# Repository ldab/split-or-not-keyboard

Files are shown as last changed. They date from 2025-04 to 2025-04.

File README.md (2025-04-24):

# split-or-not-keyboard

FoMO ZMK Ortholinear keyboard, if you can't decide between split or not.







<p align="center">
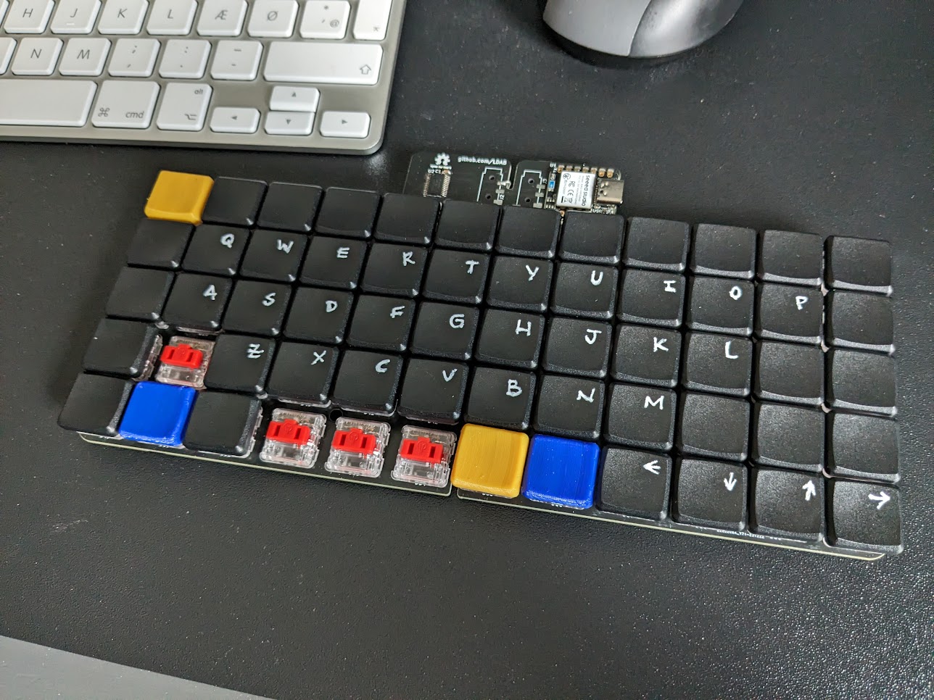
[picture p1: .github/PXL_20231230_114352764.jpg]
  
</p>

## Todo

## Note

- Polling mode add extra 60uA
-

## Why?

Maybe you are here because you are considering a ZMK keyboard and you don't know if you are ready for a split keyboard? Or you don't know if you prefer a rectangular or "ergo" design? Or you have fear or missing out and want to try all of them but don't want to spend all your money?

## How?

## Designed with KiCAD 7.09

- Important libs are added as plugin as per described on https://github.com/ebastler/marbastlib

## BOM

* 1x Seeed Studio XIAO nRF52840
* 1x PCA9555 GPIO Expander
* 60x 1N4148W diodes
* 60x Kailh choc switches
* 60x Kailh choc keycap
* 60x Kailh choc Hotswap Sockets

## Variants

### Basic60

basic

<p align="center">
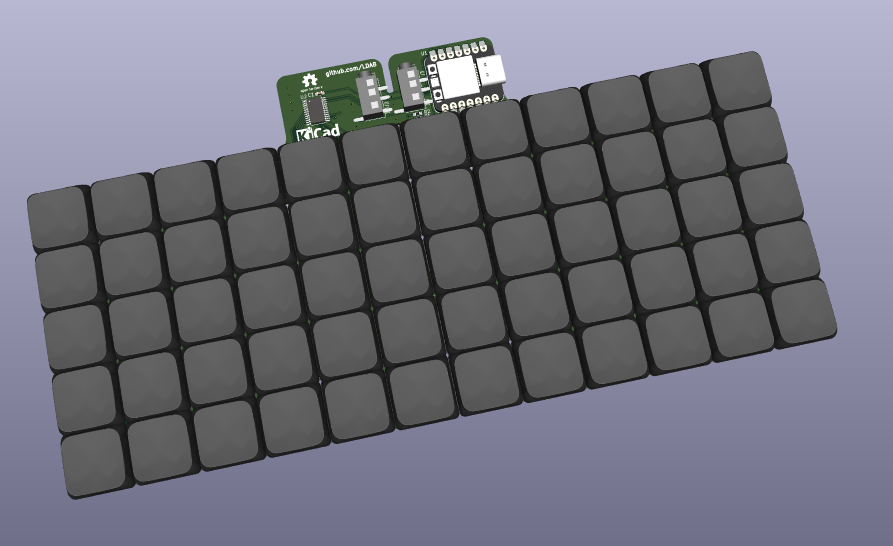
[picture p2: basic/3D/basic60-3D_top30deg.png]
  
</p>

<p align="center">
  
</p>

### Ergo56

ergo

<p align="center">
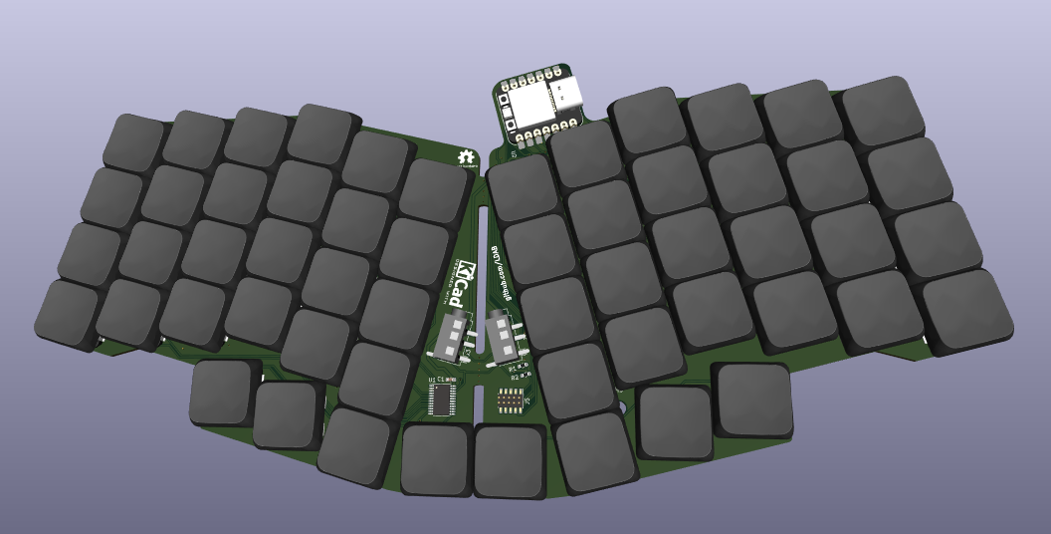
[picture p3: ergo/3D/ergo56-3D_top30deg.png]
  
</p>

<p align="center">
  
</p>

## Battery life

## Outro

- Some similarities with below may be found:
  - https://github.com/piit79/rev57lp/

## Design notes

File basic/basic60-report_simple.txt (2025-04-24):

PCB Specifications:
Size:

- 216.0x108.2 mm

Class: 8B

Track width: >= 0.25 mm

Insulation distance: >= 0.2 mm

Minimum drill size: >= 0.5 mm (finished metalized hole: 0.4 mm)

Minimum slot width: >= N/A mm

Ring collar: >= 0.1 mm

Stackup:

| Name | Type | Color | Thickness | Material | Epsilon_r | Loss tangent |
|---|---|---|---|---|---|---|
| F.SilkS | Top Silk Screen | | | | | |
| F.Paste | Top Solder Paste | | | | | |
| F.Mask | Top Solder Mask | | 10 | | | |
| F.Cu | copper | | 35 | | | |
| dielectric 1 | core | | 1510 | FR4 | 4.5 | 0.020 |
| B.Cu | copper | | 35 | | | |
| B.Mask | Bottom Solder Mask | | 10 | | | |
| B.Paste | Bottom Solder Paste  | | | | | |
| B.SilkS | Bottom Silk Screen | | | | | |

Materials:

- FR4, 1.6 mm
- None
- 2 layers
- 35 µm copper thickness

Solder mask:

- TOP / BOTTOM
- Green

Marking:

- TOP / BOTTOM screen printing
- Silk: White

Other markings:

- ROHS / UL / Date - Yes if available

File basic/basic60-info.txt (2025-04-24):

KiBot installation checker

Core:
Linux: 6.2.0.39 (Linux leo-pc 6.2.0-39-generic #40~22.04.1-Ubuntu SMP PREEMPT_DYNAMIC Thu Nov 16 10:53:04 UTC 2 x86_64 x86_64 x86_64 GNU/Linux)
  /usr/bin/uname
Python: 3.10.12 (main, Nov 20 2023, 15:14:05) [GCC 11.4.0]
  /usr/lib/python3.10/os.py
  /usr/bin/python3
KiCad: 7.0.9-7.0.9~ubuntu22.04.1
  /usr/lib/python3/dist-packages/pcbnew.py
  /usr/bin/kicad
Kibot: 1.6.3
  /usr/lib/python3/dist-packages/kibot/__main__.py
  /usr/bin/kibot

Modules:
Colorama: 0.4.4
  /usr/lib/python3/dist-packages/colorama/__init__.py
LXML: 4.8.0
  /usr/lib/python3/dist-packages/lxml/__init__.py
Lark: 1.1.8
  /home/leo/.local/lib/python3.10/site-packages/lark/__init__.py
PyYAML: 6.0.1
  /home/leo/.local/lib/python3.10/site-packages/yaml/__init__.py
QRCodeGen: Ok
  /usr/lib/python3/dist-packages/qrcodegen.py
Requests: 2.25.1
  /usr/lib/python3/dist-packages/requests/__init__.py
XLSXWriter: 3.0.2
  /usr/lib/python3/dist-packages/xlsxwriter/__init__.py
Xvfbwrapper: Ok
  /usr/lib/python3/dist-packages/xvfbwrapper.py
markdown2: 2.4.1
  /usr/lib/python3/dist-packages/markdown2.py
mistune: 0.8.4
  /usr/lib/python3/dist-packages/mistune.py
numpy: 1.21.5
  /usr/lib/python3/dist-packages/numpy/__init__.py

Tools:
Bash: 5.1.16 (GNU bash, version 5.1.16(1)-release (x86_64-pc-linux-gnu))
  /usr/bin/bash
Blender: 3.0.1 (Color management: using fallback mode for management)
  /usr/bin/blender
Ghostscript: 9.55.0
  /usr/bin/gs
Git: 2.34.1 (git version 2.34.1)
  /usr/bin/git
ImageMagick: 6.9.11.60 (Version: ImageMagick 6.9.11-60 Q16 x86_64 2021-01-25 https://imagemagick.org)
  /usr/bin/convert
Interactive HTML BoM: 2.7.0 (v2.7.0)
  /usr/bin/python3
KiBoM: 1.9.1 (KiBOM Version: 1.9.1)
  /usr/bin/KiBOM_CLI.py
KiCad Automation tools (kiauto): 2.2.8 (pcbnew_do 2.2.8 - Copyright 2018-2023, INTI/Productize SPRL - License: Apache)
  /usr/bin/pcbnew_do
KiCad PCB/SCH Diff (kidiff): 2.5.0 (kicad-diff.py 2.5.0 - Copyright 2020-2023, INTI/Salvador E. Tropea - License:)
  /usr/bin/kicad-diff.py
KiCost: 1.1.18 (KiCost v1.1.18)
  /usr/bin/kicost
KiKit: 1.4.0.1 (kikit, version 1.4.0-1)
  /usr/bin/kikit
OpenSCAD: 2021.1.0 (OpenSCAD version 2021.01)
  /usr/bin/openscad
Pandoc: 2.9.2.1 (pandoc 2.9.2.1)
  /usr/bin/pandoc
RAR: 5.50.0 (RAR 5.50   Copyright (c) 1993-2017 Alexander Roshal   11 Aug 2017)
  /usr/bin/rar
RSVG tools: 2.52.5 (rsvg-convert version 2.52.5)
  /usr/bin/rsvg-convert
Xvfb: Ok (xvfb-run)
  /usr/bin/rsvg-convert

* Blender not installed or too old
  Install the `blender` package, i.e.: `sudo apt-get install blender`
  - Mandatory for `blender_export`

Environment:
COLORFGBG
COLORTERM
DBUS_SESSION_BUS_ADDRESS
DESKTOP_SESSION
DISPLAY
GDMSESSION
GIO_LAUNCHED_DESKTOP_FILE
GIO_LAUNCHED_DESKTOP_FILE_PID
GITHUB_TOKEN
GJS_DEBUG_OUTPUT
GJS_DEBUG_TOPICS
GNOME_DESKTOP_SESSION_ID
GNOME_SHELL_SESSION_MODE
GPG_AGENT_INFO
GTK_IM_MODULE
GTK_MODULES
HISTCONTROL
HOME
HOMEBREW_CELLAR
HOMEBREW_PREFIX
HOMEBREW_REPOSITORY
INFOPATH
INTERACTIVE_HTML_BOM_NO_DISPLAY
INVOCATION_ID
JOURNAL_STREAM
KICAD6_3DMODEL_DIR
KICAD6_3RD_PARTY
KICAD6_FOOTPRINT_DIR
KICAD6_SYMBOL_DIR
KICAD6_TEMPLATE_DIR
KICAD7_3DMODEL_DIR
KICAD7_3RD_PARTY
KICAD7_FOOTPRINT_DIR
KICAD7_SYMBOL_DIR
KICAD7_TEMPLATE_DIR
KICAD_USER_TEMPLATE_DIR
KIPRJMOD
KISYS3DMOD
KISYSMOD
KONSOLE_DBUS_SERVICE
KONSOLE_DBUS_SESSION
KONSOLE_DBUS_WINDOW
KONSOLE_VERSION
LANG
LANGUAGE
LC_ADDRESS
LC_IDENTIFICATION
LC_MEASUREMENT
LC_MONETARY
LC_NAME
LC_NUMERIC
LC_PAPER
LC_TELEPHONE
LC_TIME
LESSCLOSE
LESSOPEN
LOGNAME
LS_COLORS
MANAGERPID
MANPATH
MCFLY_FUZZY
MCFLY_HISTFILE
MCFLY_HISTORY
MCFLY_SESSION_ID
OLDPWD
PAPERSIZE
PATH
PROFILEHOME
PWD
PYTHONPATH
QTWEBENGINE_CHROMIUM_FLAGS
QT_ACCESSIBILITY
QT_DEBUG_PLUGINS
QT_IM_MODULE
SESSION_MANAGER
SHELL
SHELL_SESSION_ID
SHLVL
SSH_AGENT_LAUNCHER
SSH_AUTH_SOCK
SYSTEMD_EXEC_PID
TERM
USER
USERNAME
WINDOWID
WINDOWPATH
XAUTHORITY
XDG_CONFIG_DIRS
XDG_CURRENT_DESKTOP
XDG_DATA_DIRS
XDG_MENU_PREFIX
XDG_RUNTIME_DIR
XDG_SESSION_CLASS
XDG_SESSION_DESKTOP
XDG_SESSION_TYPE
XMODIFIERS
_

KiAuto:
This is KiAuto v2.2.8
Installed at: /usr/bin/pcbnew_do
Using kiauto module from: /usr/lib/python3/dist-packages/kiauto
Interpreted by Python: /usr/bin/python3 (v3.10.12 (main, Nov 20 2023, 15:14:05) [GCC 11.4.0])
Tools:
- kicad: /usr/bin/kicad (v7.0.9-7.0.9~ubuntu22.04.1)
- xdotool: /usr/bin/xdotool
- recordmydesktop: /usr/bin/recordmydesktop
- xsltproc: /usr/bin/xsltproc
- xclip: /usr/bin/xclip
- convert: /usr/bin/convert

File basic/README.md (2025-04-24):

# split-or-not-keyboard
FoMO ZMK Ortholinear keyboard, if you can't decide between split or not.







<p align="center">
  
</p>

## Todo

## Why?

Maybe you are here because you are considering a ZMK keyboard and you don't know if you are ready for a split keyboard? Or you don't know if you prefer a rectangular or "ergo" design? Or you have fear or missing out and want to try all of them but don't want to spend all your money?

## How?

<p align="center">
  
</p>

## Designed with KiCAD 7.09

* Important libs are added as plugin as per described on https://github.com/ebastler/marbastlib

## Outro

* Some similarities with below may be found:
  * https://github.com/piit79/rev57lp/
  * https://github.com/MakotoKurauchi/helix

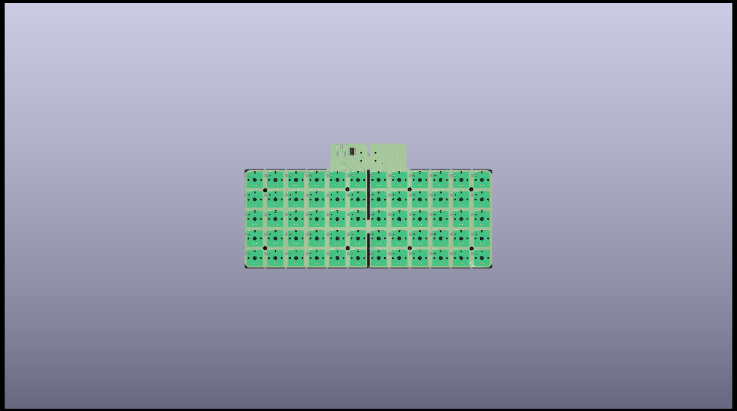
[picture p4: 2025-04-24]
basic/3D/basic60-3D_bottom.png

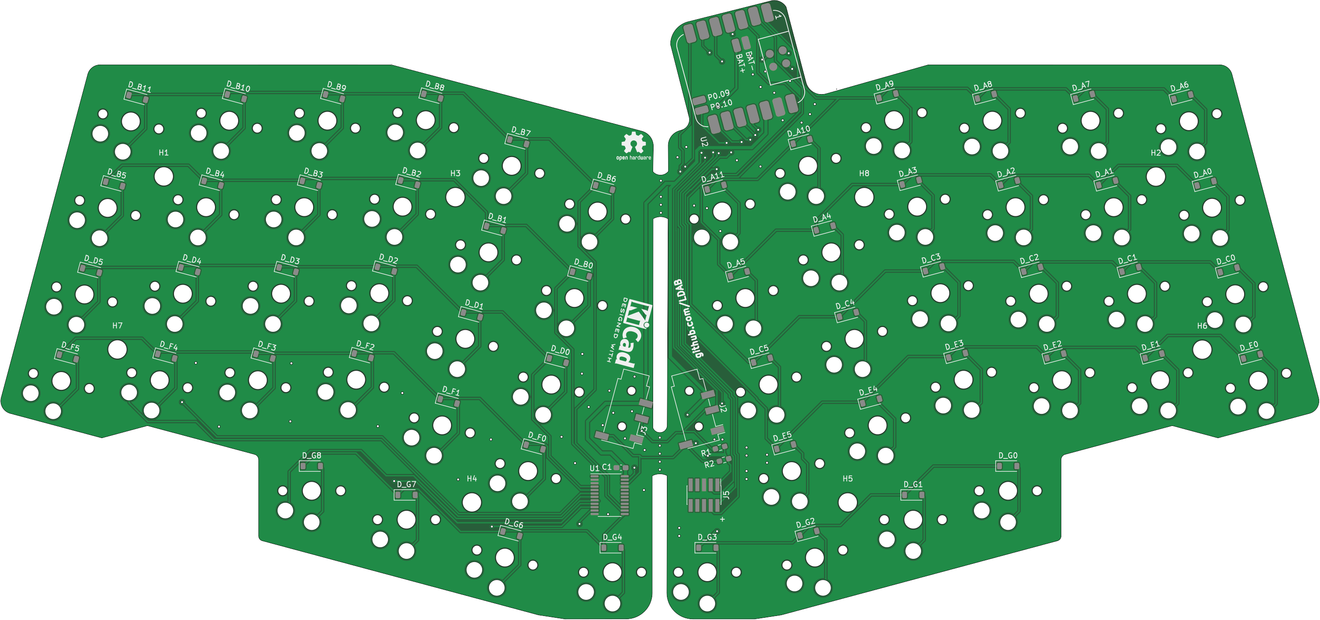
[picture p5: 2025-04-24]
ergo/PCB/2D_render/jlcpcb_green_enig/ergo56-top.png

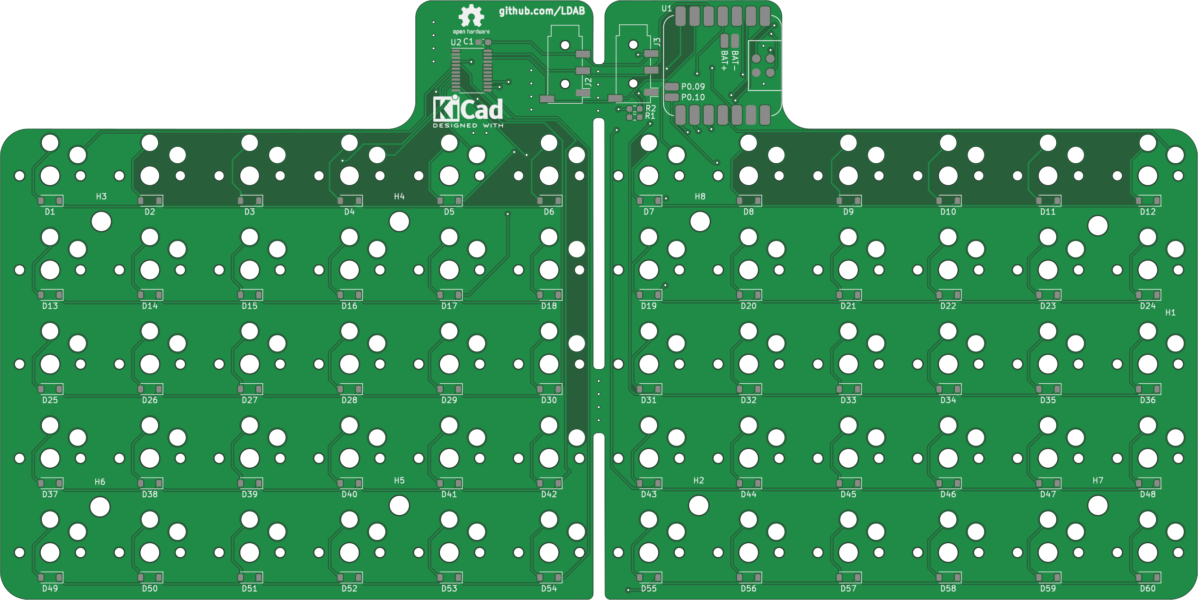
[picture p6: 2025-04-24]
basic/PCB/2D_render/jlcpcb_green_enig/basic60-top.png

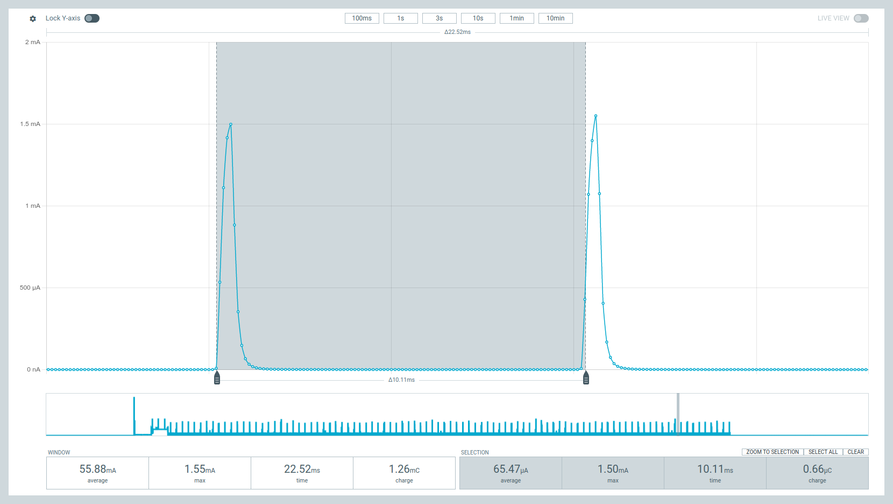
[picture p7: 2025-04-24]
.github/ppk-20240103T101734.png

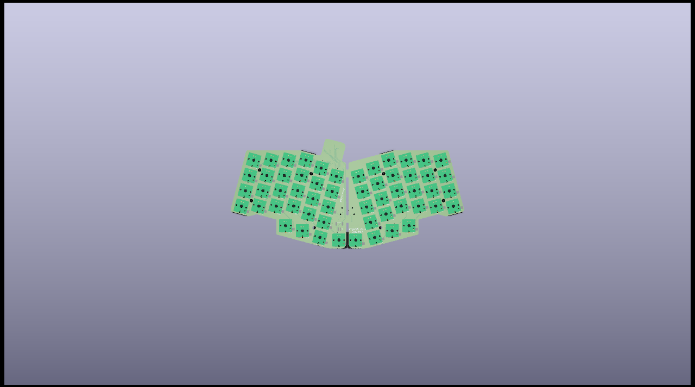
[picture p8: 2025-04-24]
ergo/3D/ergo56-3D_bottom.png

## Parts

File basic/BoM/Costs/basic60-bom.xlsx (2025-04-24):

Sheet: BoM
 |  | KiBot Bill of Materials
 |  | Schematic: | basic60 | Component Groups: | 7
 |  | Variant: | default | Component Count: | 127 (127 SMD/ 0 THT)
 |  | Revision: | 0.1 | Fitted Components: | 127 (127 SMD/ 0 THT)
 |  | Date: | 2023-12-20 | Number of PCBs: | 1
 |  | KiCad Version: | 7.0.9-7.0.9~ubuntu22.04.1 | Total Components: | 127
Row | Description | Part | References | Value | Footprint | Quantity Per PCB | Status | Datasheet | Sim.Device | Sim.Pins | Sim.Enable
1 | Unpolarized capacitor, small symbol | C_Small | C1 | 100n | C_0603_1608Metric_Pad1.08x0.95mm_HandSolder | 1 |  | ~
2 | 75V 0.15A Fast Switching Diode, SOD-123 | 1N4148W | D1 D2 D3 D4 D5 D6 D7 D8 D9 D10 D11 D12 D13 D14 D15 D16 D17 D18 D19 D20 D21 D22 D23 D24 D25 D26 D27 D28 D29 D30 D31 D32 D33 D34 D35 D36 D37 D38 D39 D40 D41 D42 D43 D44 D45 D46 D47 D48 D49 D50 D51 D52 D53 D54 D55 D56 D57 D58 D59 D60 | ~ | D_SOD-123 | 60 |  | https://www.vishay.com/docs/85748/1n4148w.pdf | D | 1=K 2=A
3 | Audio Jack, 3 Poles (Stereo / TRS), Grounded Sleeve | AudioJack3_Ground | J2 J3 | AudioJack3_Ground | Jack_3.5mm_PJ320D_Horizontal | 2 |  | ~
4 | Generic connector, single row, 01x02, script generated (kicad-library-utils/schlib/autogen/connector/) | Conn_01x02 | J4 | BAT | JST_PH_S2B-PH-SM4-TB_1x02-1MP_P2.00mm_Horizontal | 1 |  | ~
5 | Resistor, small symbol | R_Small | R1 R2 | 10K | R_0603_1608Metric_Pad0.98x0.95mm_HandSolder | 2 |  | ~
6 | Push button switch, generic, two pins | SW_Push | SW1 SW2 SW3 SW4 SW5 SW6 SW7 SW8 SW9 SW10 SW11 SW12 SW13 SW14 SW15 SW16 SW17 SW18 SW19 SW20 SW21 SW22 SW23 SW24 SW25 SW26 SW27 SW28 SW29 SW30 SW31 SW32 SW33 SW34 SW35 SW36 SW37 SW38 SW39 SW40 SW41 SW42 SW43 SW44 SW45 SW46 SW47 SW48 SW49 SW50 SW51 SW52 SW53 SW54 SW55 SW56 SW57 SW58 SW59 SW60 | SW_Push | SW_choc_v1_HS_1u | 60 |  | ~
7 | IO expander 16 GPIO, I2C 400kHz, Interrupt, 2.3 - 5.5V, TSSOP-24 | PCA9555PW | U2 | PCA9555PW | TSSOP-24_4.4x7.8mm_P0.65mm | 1 |  | https://www.nxp.com/docs/en/data-sheet/PCA9555.pdf

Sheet: Costs
 |  |  | KiBot Bill of Materials
 |  |  | Schematic: | basic60 | Board Qty: | 1
 |  |  | Variant: | default | Unit Cost: | $0.00
 |  |  | Revision: | 0.1 | Total Cost: | $0.00
 |  |  | Date: | 2023-12-20
 |  |  | KiCad Version: | 7.0.9-7.0.9~ubuntu22.04.1
Global Part Info
References | Value | Footprint | Manf# | Build Quantity | Unit$ | Ext$
C1 | 100n | C_0603_1608Metric_Pad1.08x0.95mm_HandSolder |  | 1
D1 D2 D3 D4 D5 D6 D7 D8 D9 D10 D11 D12 D13 D14 D15 D16 D17 D18 D19 D20 D21 D22 D23 D24 D25 D26 D27 D28 D29 D30 D31 D32 D33 D34 D35 D36 D37 D38 D39 D40 D41 D42 D43 D44 D45 D46 D47 D48 D49 D50 D51 D52 D53 D54 D55 D56 D57 D58 D59 D60 | ~ | D_SOD-123 | https://www.vishay.com/docs/85748/1n4148w.pdf | 60
J2 J3 | AudioJack3_Ground | Jack_3.5mm_PJ320D_Horizontal |  | 2
J4 | BAT | JST_PH_S2B-PH-SM4-TB_1x02-1MP_P2.00mm_Horizontal |  | 1
R1 R2 | 10K | R_0603_1608Metric_Pad0.98x0.95mm_HandSolder |  | 2
SW1 SW2 SW3 SW4 SW5 SW6 SW7 SW8 SW9 SW10 SW11 SW12 SW13 SW14 SW15 SW16 SW17 SW18 SW19 SW20 SW21 SW22 SW23 SW24 SW25 SW26 SW27 SW28 SW29 SW30 SW31 SW32 SW33 SW34 SW35 SW36 SW37 SW38 SW39 SW40 SW41 SW42 SW43 SW44 SW45 SW46 SW47 SW48 SW49 SW50 SW51 SW52 SW53 SW54 SW55 SW56 SW57 SW58 SW59 SW60 | SW_Push | SW_choc_v1_HS_1u |  | 60
U2 | PCA9555PW | TSSOP-24_4.4x7.8mm_P0.65mm | https://www.nxp.com/docs/en/data-sheet/PCA9555.pdf | 1
Created: | 2023-12-21 23:36:55
KiCost® v1.1.18 + KiBot v1.6.3

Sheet: Colors
KiCad Fields (default)
Generated Fields
User Fields
Empty Fields
Costs sheet
Best price
No manufacturer or distributor code
Not available
Purchase quantity is more than what is available
Minimum order quantity not respected
Total available part quantity is less than needed
Total purchased part quantity is less than needed
This part is obsolete
This part is listed but is not normally stocked

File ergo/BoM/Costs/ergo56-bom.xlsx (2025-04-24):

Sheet: BoM
 |  | KiBot Bill of Materials
 |  | Schematic: | ergo56 | Component Groups: | 7
 |  | Variant: | default | Component Count: | 119 (119 SMD/ 0 THT)
 |  | Revision: | 0.1 | Fitted Components: | 119 (119 SMD/ 0 THT)
 |  | Date: | 2023-12-20 | Number of PCBs: | 1
 |  | KiCad Version: | 7.0.9-7.0.9~ubuntu22.04.1 | Total Components: | 119
Row | Description | Part | References | Value | Footprint | Quantity Per PCB | Status | Datasheet | Sim.Device | Sim.Pins | Sim.Enable
1 | Unpolarized capacitor, small symbol | C_Small | C1 | 100n | C_0603_1608Metric_Pad1.08x0.95mm_HandSolder | 1 |  | ~
2 | 75V 0.15A Fast Switching Diode, SOD-123 | 1N4148W | D_A0 D_A1 D_A2 D_A3 D_A4 D_A5 D_A6 D_A7 D_A8 D_A9 D_A10 D_A11 D_B0 D_B1 D_B2 D_B3 D_B4 D_B5 D_B6 D_B7 D_B8 D_B9 D_B10 D_B11 D_C0 D_C1 D_C2 D_C3 D_C4 D_C5 D_D0 D_D1 D_D2 D_D3 D_D4 D_D5 D_E0 D_E1 D_E2 D_E3 D_E4 D_E5 D_F0 D_F1 D_F2 D_F3 D_F4 D_F5 D_G0 D_G1 D_G2 D_G3 D_G4 D_G6 D_G7 D_G8 | ~ | D_SOD-123 | 56 |  | https://www.vishay.com/docs/85748/1n4148w.pdf | D | 1=K 2=A
3 | Audio Jack, 3 Poles (Stereo / TRS), Grounded Sleeve | AudioJack3_Ground | J2 J3 | AudioJack3_Ground | Jack_3.5mm_PJ320D_Horizontal | 2 |  | ~
4 | Generic connector, single row, 01x02, script generated (kicad-library-utils/schlib/autogen/connector/) | Conn_01x02 | J1 | BAT | JST_PH_S2B-PH-SM4-TB_1x02-1MP_P2.00mm_Horizontal | 1 |  | ~
5 | Resistor, small symbol | R_Small | R1 R2 | 10K | R_0603_1608Metric_Pad0.98x0.95mm_HandSolder | 2 |  | ~
6 | Push button switch, generic, two pins | SW_Push | SwA0 SwA1 SwA2 SwA3 SwA4 SwA5 SwA6 SwA7 SwA8 SwA9 SwA10 SwA11 SwB0 SwB1 SwB2 SwB3 SwB4 SwB5 SwB6 SwB7 SwB8 SwB9 SwB10 SwB11 SwC0 SwC1 SwC2 SwC3 SwC4 SwC5 SwD0 SwD1 SwD2 SwD3 SwD4 SwD5 SwE0 SwE1 SwE2 SwE3 SwE4 SwE5 SwF0 SwF1 SwF2 SwF3 SwF4 SwF5 SwG0 SwG1 SwG2 SwG3 SwG4 SwG6 SwG7 SwG8 | SW_Push | SW_choc_v1_HS_1u | 56 |  | ~
7 | IO expander 16 GPIO, I2C 400kHz, Interrupt, 2.3 - 5.5V, TSSOP-24 | PCA9555PW | U1 | PCA9555PW | TSSOP-24_4.4x7.8mm_P0.65mm | 1 |  | https://www.nxp.com/docs/en/data-sheet/PCA9555.pdf

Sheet: Costs
 |  |  | KiBot Bill of Materials
 |  |  | Schematic: | ergo56 | Board Qty: | 1
 |  |  | Variant: | default | Unit Cost: | $0.00
 |  |  | Revision: | 0.1 | Total Cost: | $0.00
 |  |  | Date: | 2023-12-20
 |  |  | KiCad Version: | 7.0.9-7.0.9~ubuntu22.04.1
Global Part Info
References | Value | Footprint | Manf# | Build Quantity | Unit$ | Ext$
C1 | 100n | C_0603_1608Metric_Pad1.08x0.95mm_HandSolder |  | 1
D_A0 D_A1 D_A2 D_A3 D_A4 D_A5 D_A6 D_A7 D_A8 D_A9 D_A10 D_A11 D_B0 D_B1 D_B2 D_B3 D_B4 D_B5 D_B6 D_B7 D_B8 D_B9 D_B10 D_B11 D_C0 D_C1 D_C2 D_C3 D_C4 D_C5 D_D0 D_D1 D_D2 D_D3 D_D4 D_D5 D_E0 D_E1 D_E2 D_E3 D_E4 D_E5 D_F0 D_F1 D_F2 D_F3 D_F4 D_F5 D_G0 D_G1 D_G2 D_G3 D_G4 D_G6 D_G7 D_G8 | ~ | D_SOD-123 | https://www.vishay.com/docs/85748/1n4148w.pdf | 56
J2 J3 | AudioJack3_Ground | Jack_3.5mm_PJ320D_Horizontal |  | 2
J1 | BAT | JST_PH_S2B-PH-SM4-TB_1x02-1MP_P2.00mm_Horizontal |  | 1
R1 R2 | 10K | R_0603_1608Metric_Pad0.98x0.95mm_HandSolder |  | 2
SwA0 SwA1 SwA2 SwA3 SwA4 SwA5 SwA6 SwA7 SwA8 SwA9 SwA10 SwA11 SwB0 SwB1 SwB2 SwB3 SwB4 SwB5 SwB6 SwB7 SwB8 SwB9 SwB10 SwB11 SwC0 SwC1 SwC2 SwC3 SwC4 SwC5 SwD0 SwD1 SwD2 SwD3 SwD4 SwD5 SwE0 SwE1 SwE2 SwE3 SwE4 SwE5 SwF0 SwF1 SwF2 SwF3 SwF4 SwF5 SwG0 SwG1 SwG2 SwG3 SwG4 SwG6 SwG7 SwG8 | SW_Push | SW_choc_v1_HS_1u |  | 56
U1 | PCA9555PW | TSSOP-24_4.4x7.8mm_P0.65mm | https://www.nxp.com/docs/en/data-sheet/PCA9555.pdf | 1
Created: | 2023-12-21 16:17:44
KiCost® v1.1.18 + KiBot v1.6.3

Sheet: Colors
KiCad Fields (default)
Generated Fields
User Fields
Empty Fields
Costs sheet
Best price
No manufacturer or distributor code
Not available
Purchase quantity is more than what is available
Minimum order quantity not respected
Total available part quantity is less than needed
Total purchased part quantity is less than needed
This part is obsolete
This part is listed but is not normally stocked

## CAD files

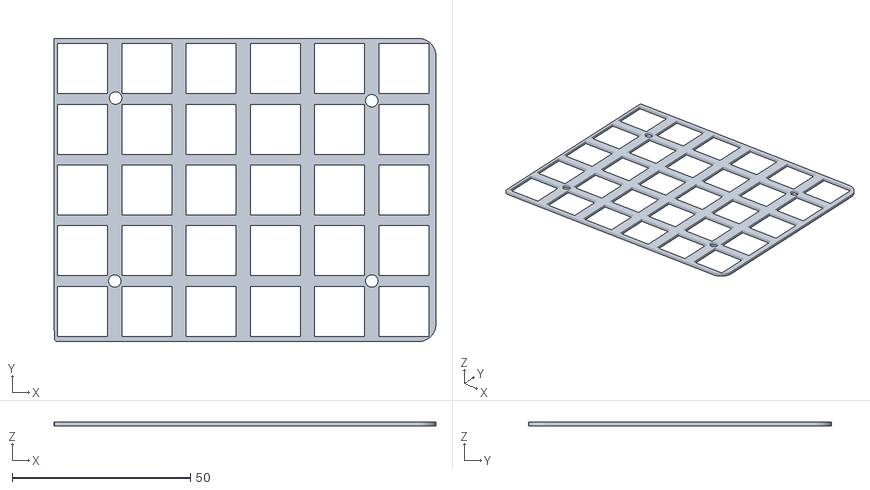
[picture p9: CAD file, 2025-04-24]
basic/Plate/top_plate.stl
107.0 x 85.0 x 1.20

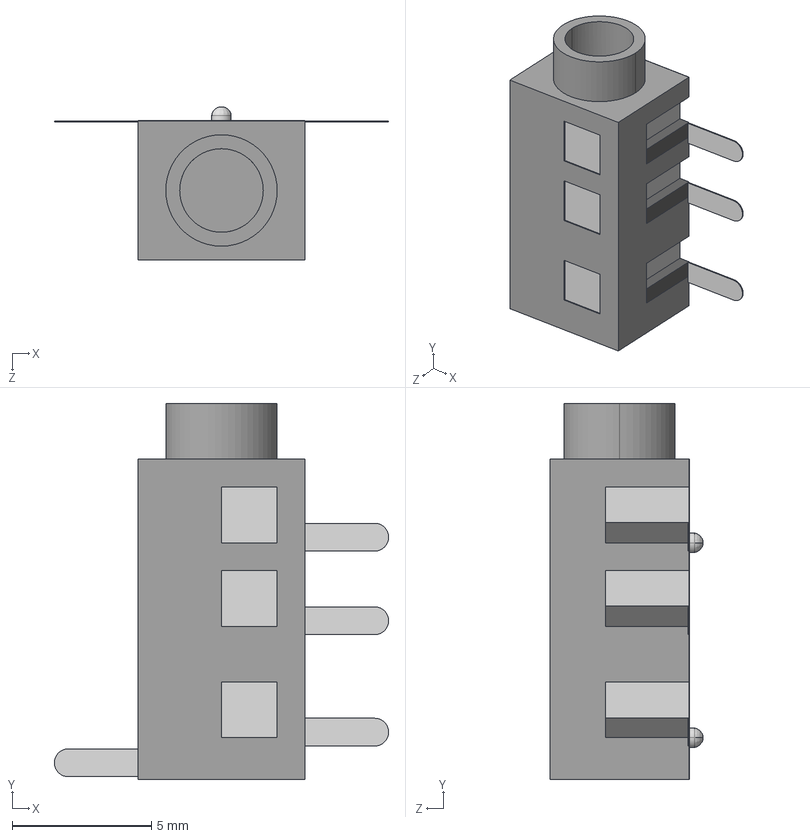
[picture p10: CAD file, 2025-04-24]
utils/audio_3.5mm_trrs.STEP
12.0 x 13.5 x 5.50 mm
Composant1.step
audio_3.5mm_trrs.step
audio_3.5mm_trrs-0.step
audio_3.5mm_trrs-1.step
audio_3.5mm_trrs-2.step
audio_3.5mm_trrs-3.step
audio_3.5mm_trrs-4.step
audio_3.5mm_trrs-5.step
audio_3.5mm_trrs-6.step
audio_3.5mm_trrs-7.step
audio_3.5mm_trrs-8.step
audio_3.5mm_trrs-9.step
audio_3.5mm_trrs-10.step
audio_3.5mm_trrs-11.step
audio_3.5mm_trrs-12.step
audio_3.5mm_trrs-13.step

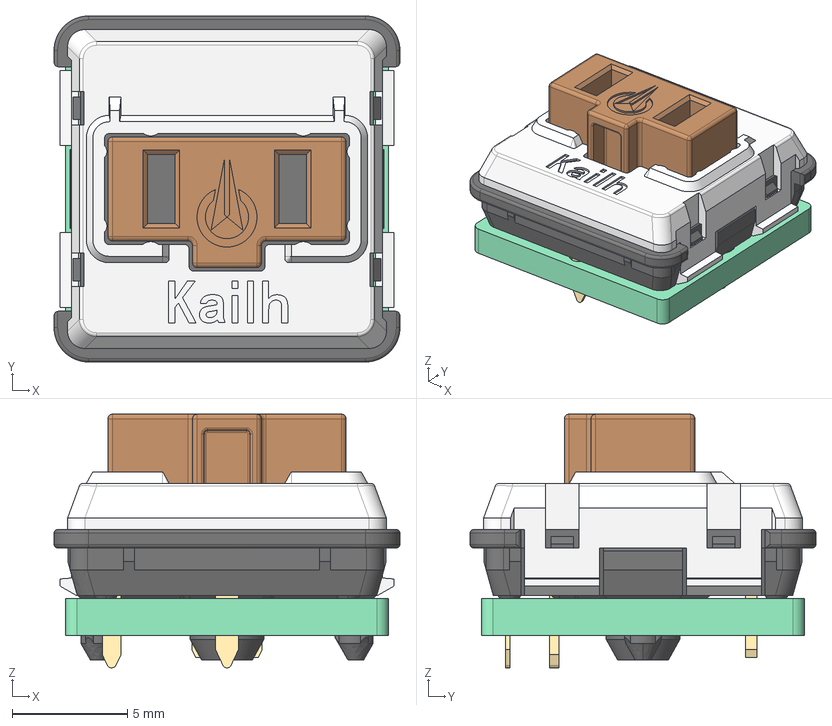
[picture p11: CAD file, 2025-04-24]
utils/Kailh Choc Low Profile Switch.step
15.0 x 15.0 x 11.0 mm

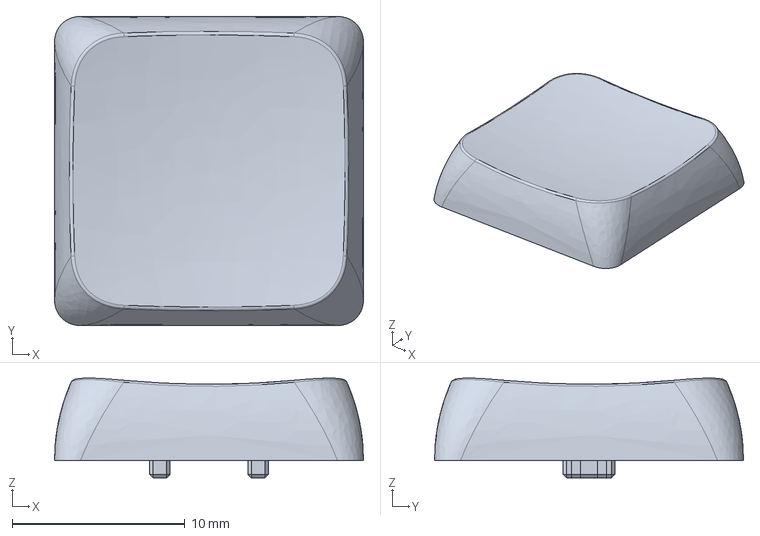
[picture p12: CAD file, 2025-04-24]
utils/Kailh Choc FunkMonk 1u.step
17.9 x 17.9 x 5.78 mm

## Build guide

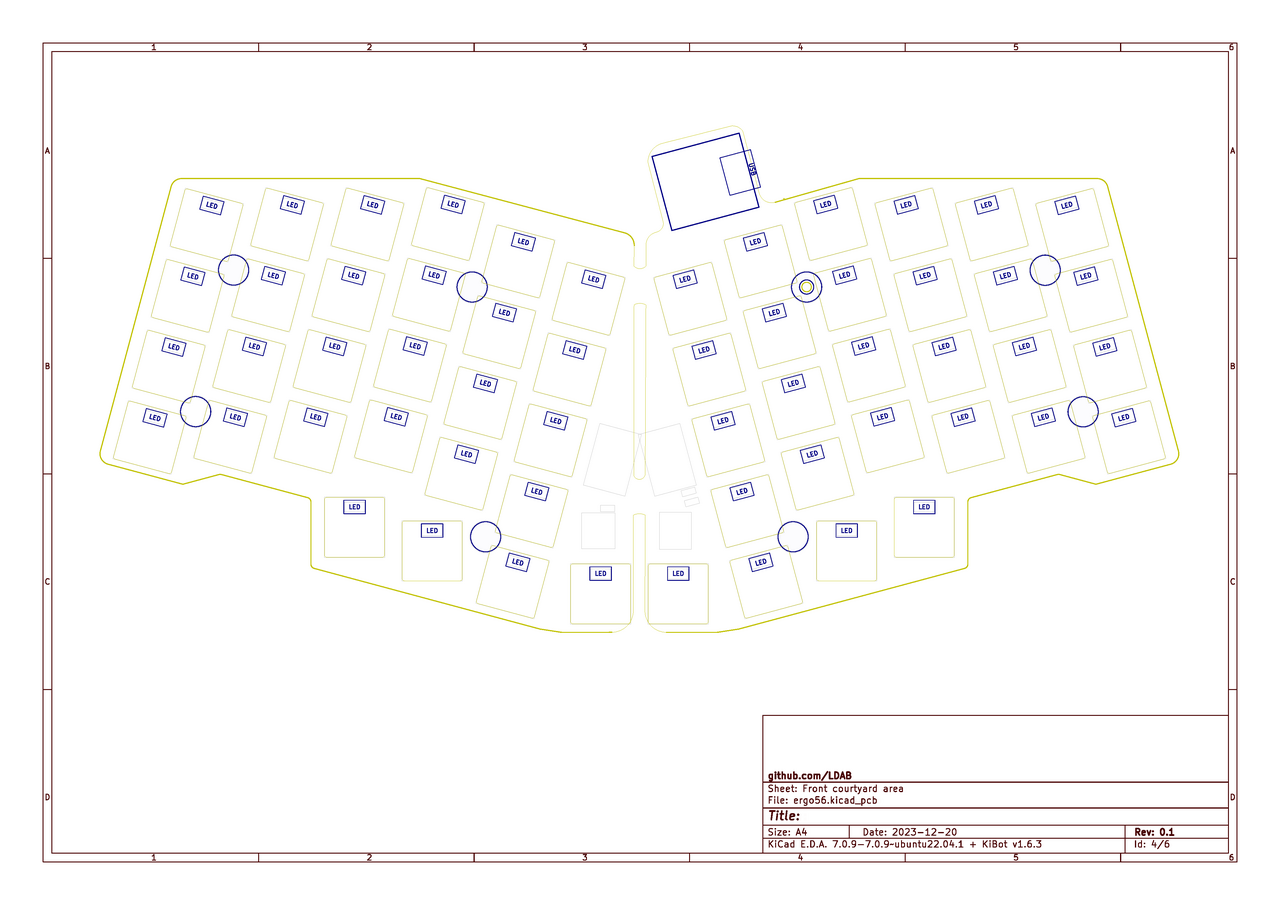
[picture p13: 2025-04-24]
ergo/PCB/PNG/ergo56-assembly_page_04.png

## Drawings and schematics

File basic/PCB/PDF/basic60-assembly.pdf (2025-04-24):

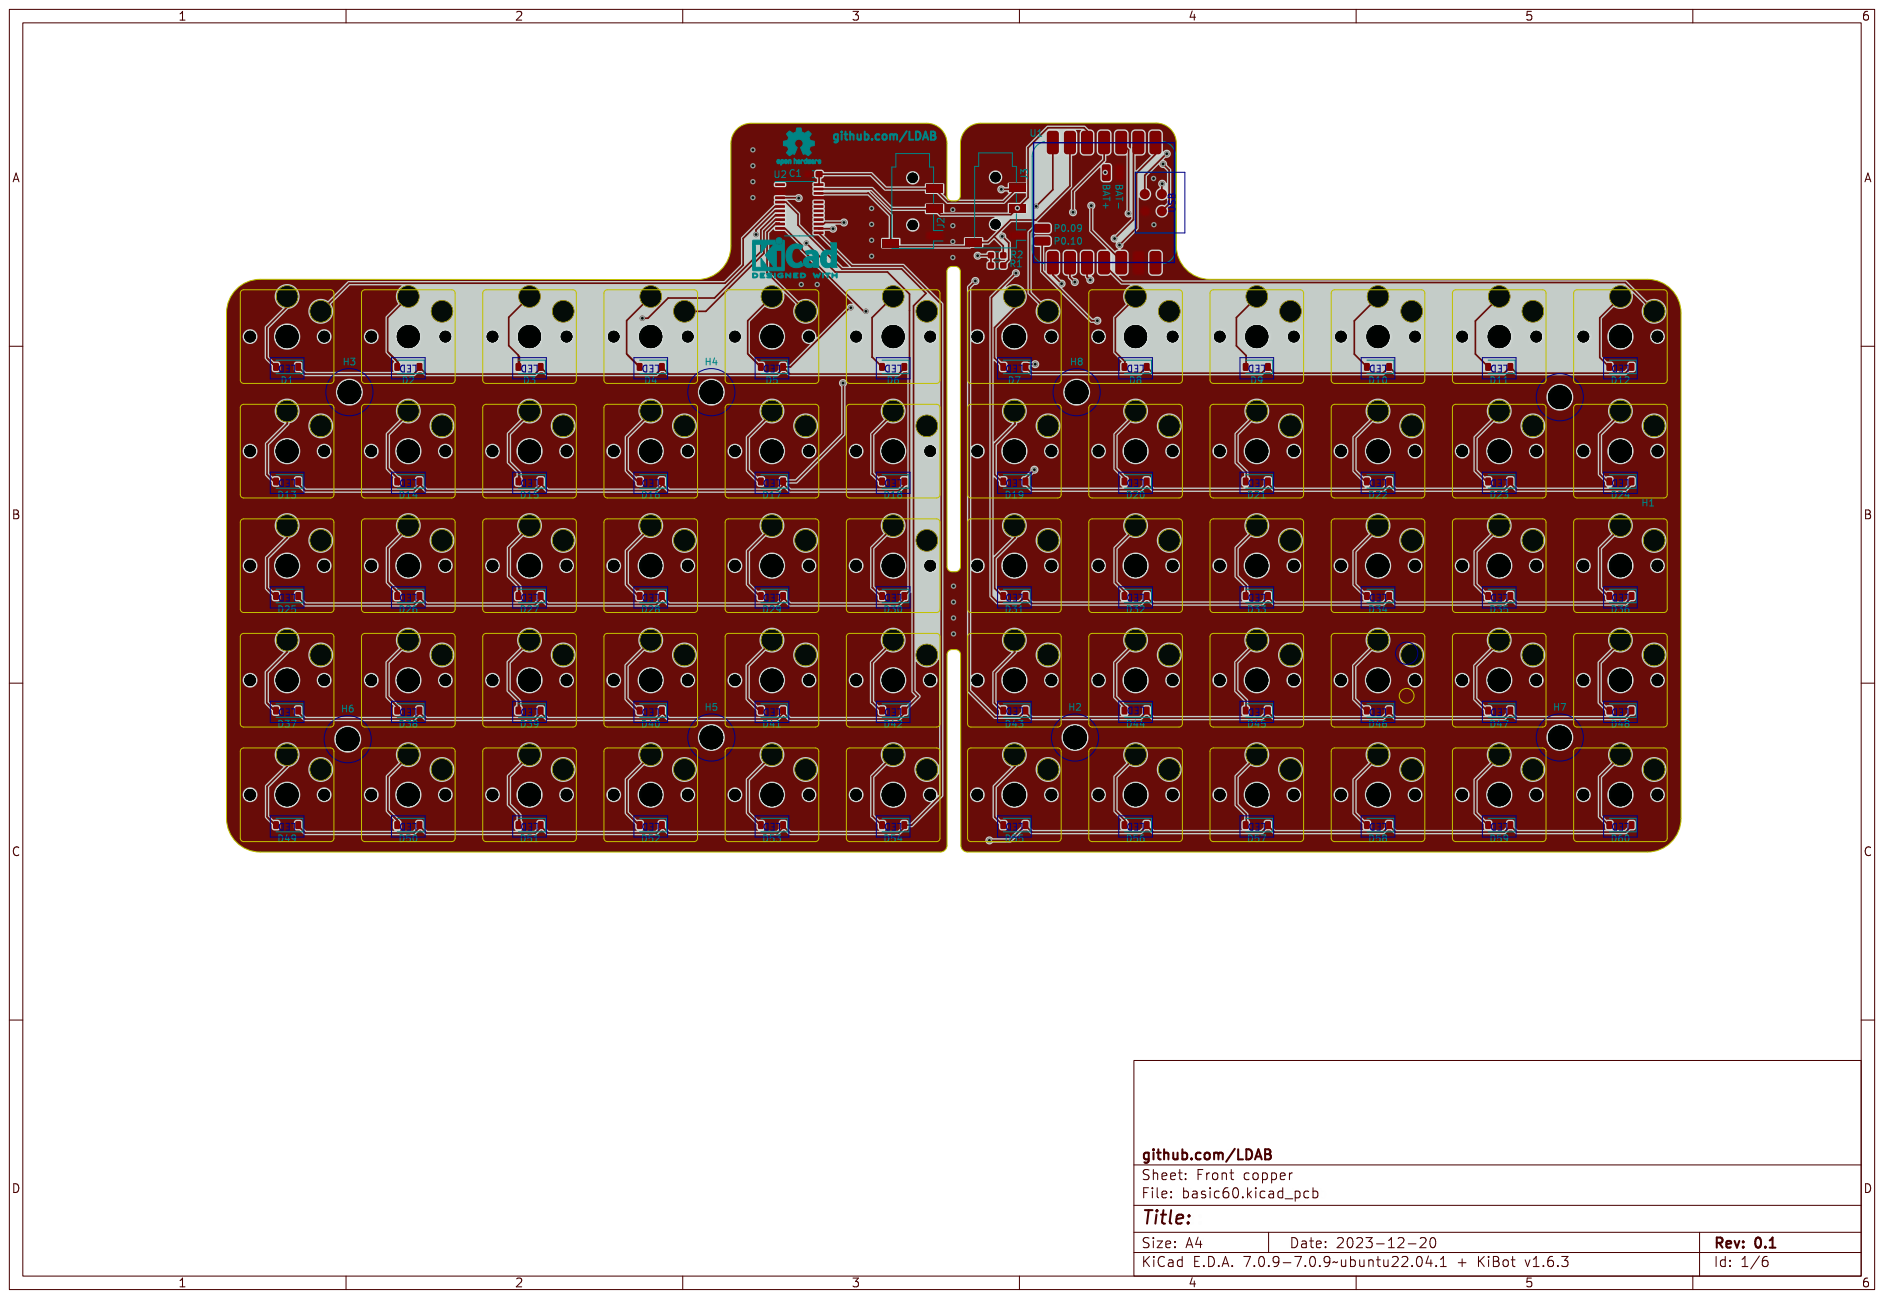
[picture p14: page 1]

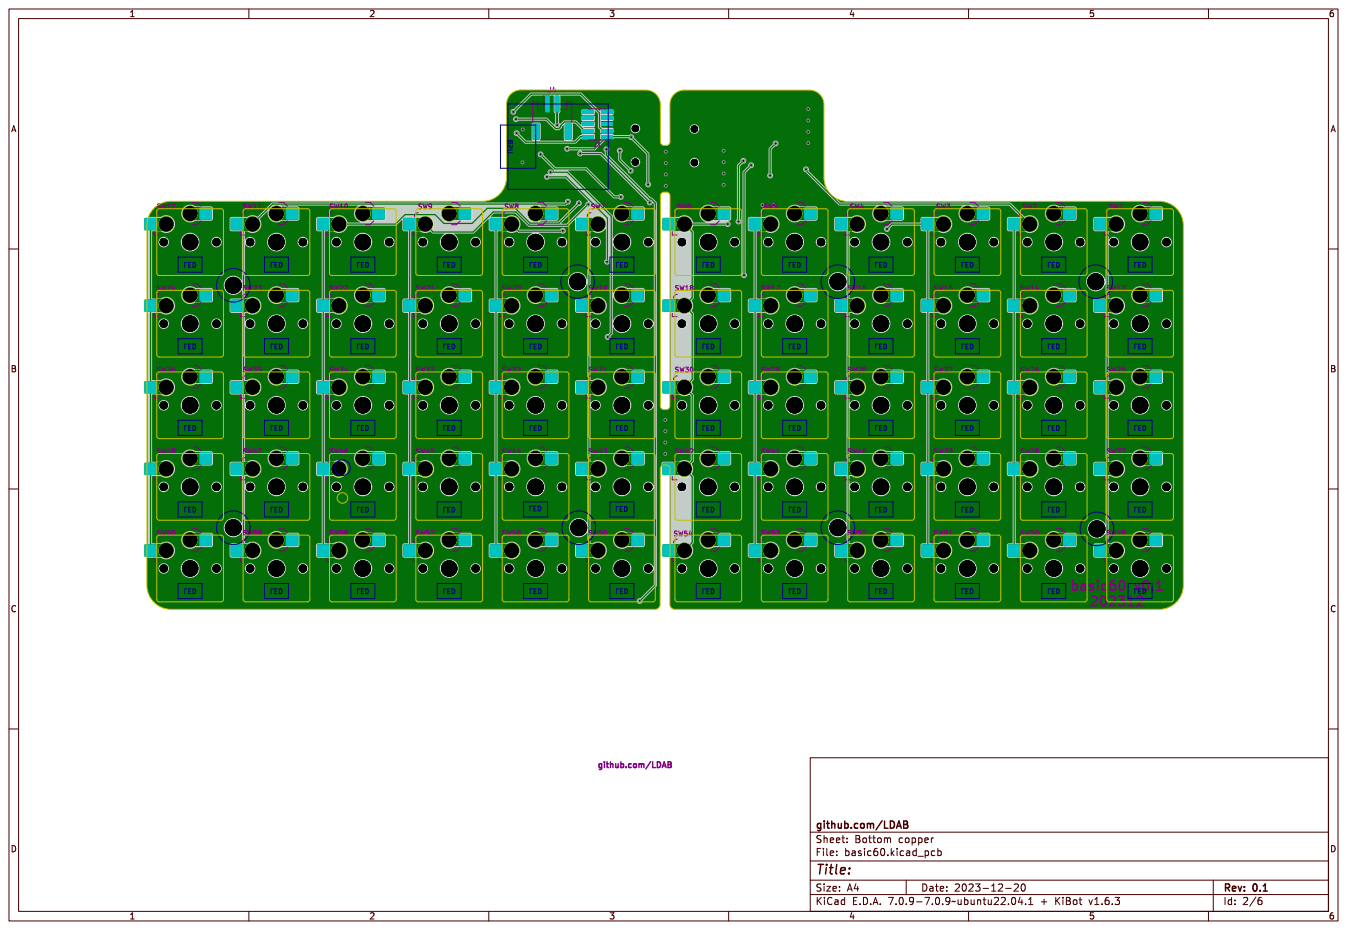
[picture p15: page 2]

github.com/LDAB
Sheet: Bottom copper
File: basic60.kicad_pcb
Title:

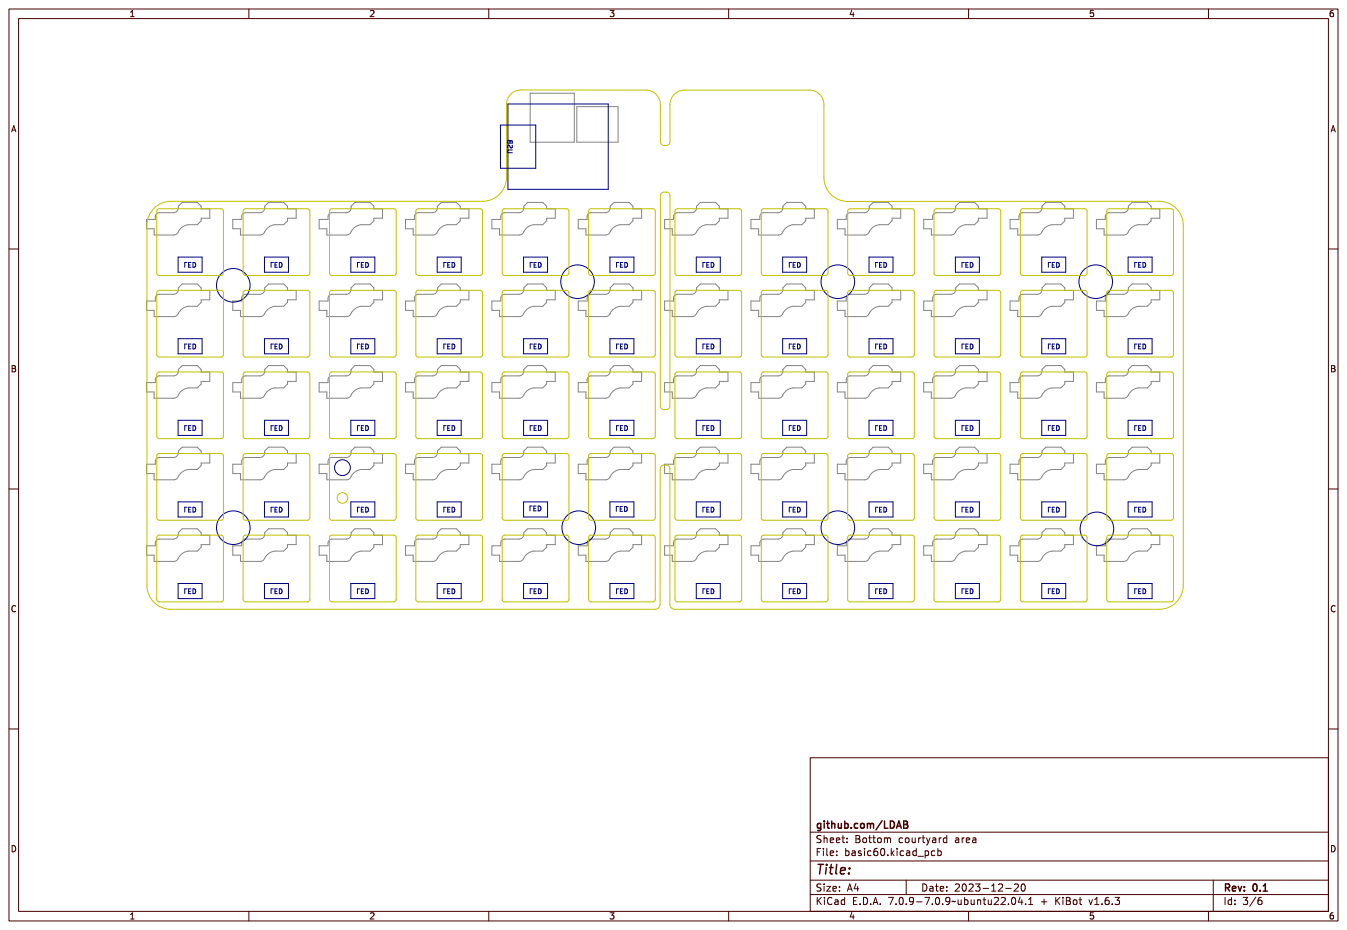
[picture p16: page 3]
Sheet:; Bottom courtyard area; File:; basic60.kicad_pcb

github.com/LDAB
Title:

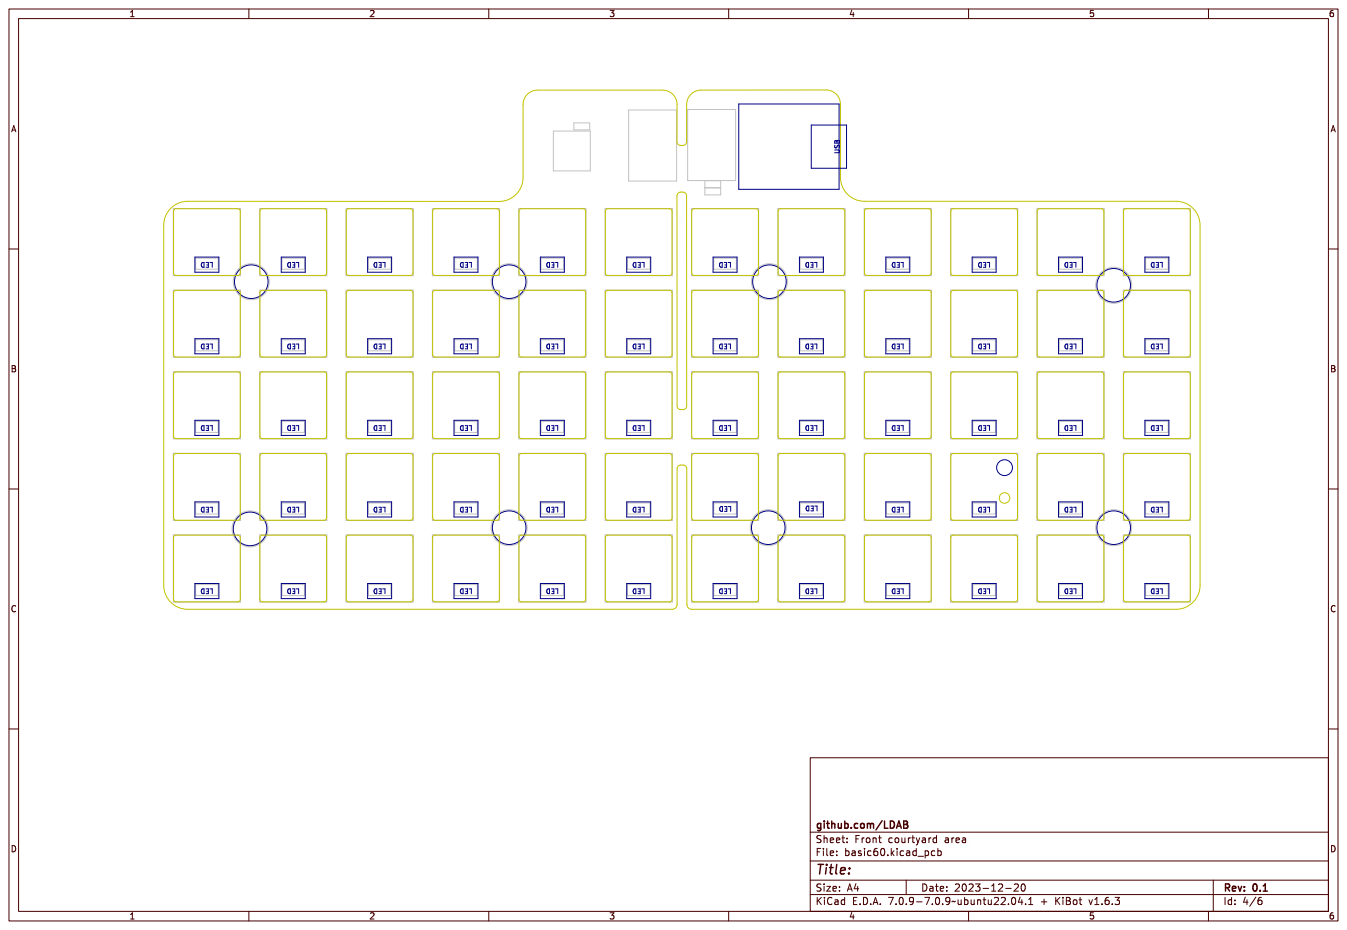
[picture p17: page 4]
Sheet:; Front courtyard area; File:; basic60.kicad_pcb

github.com/LDAB
Title:

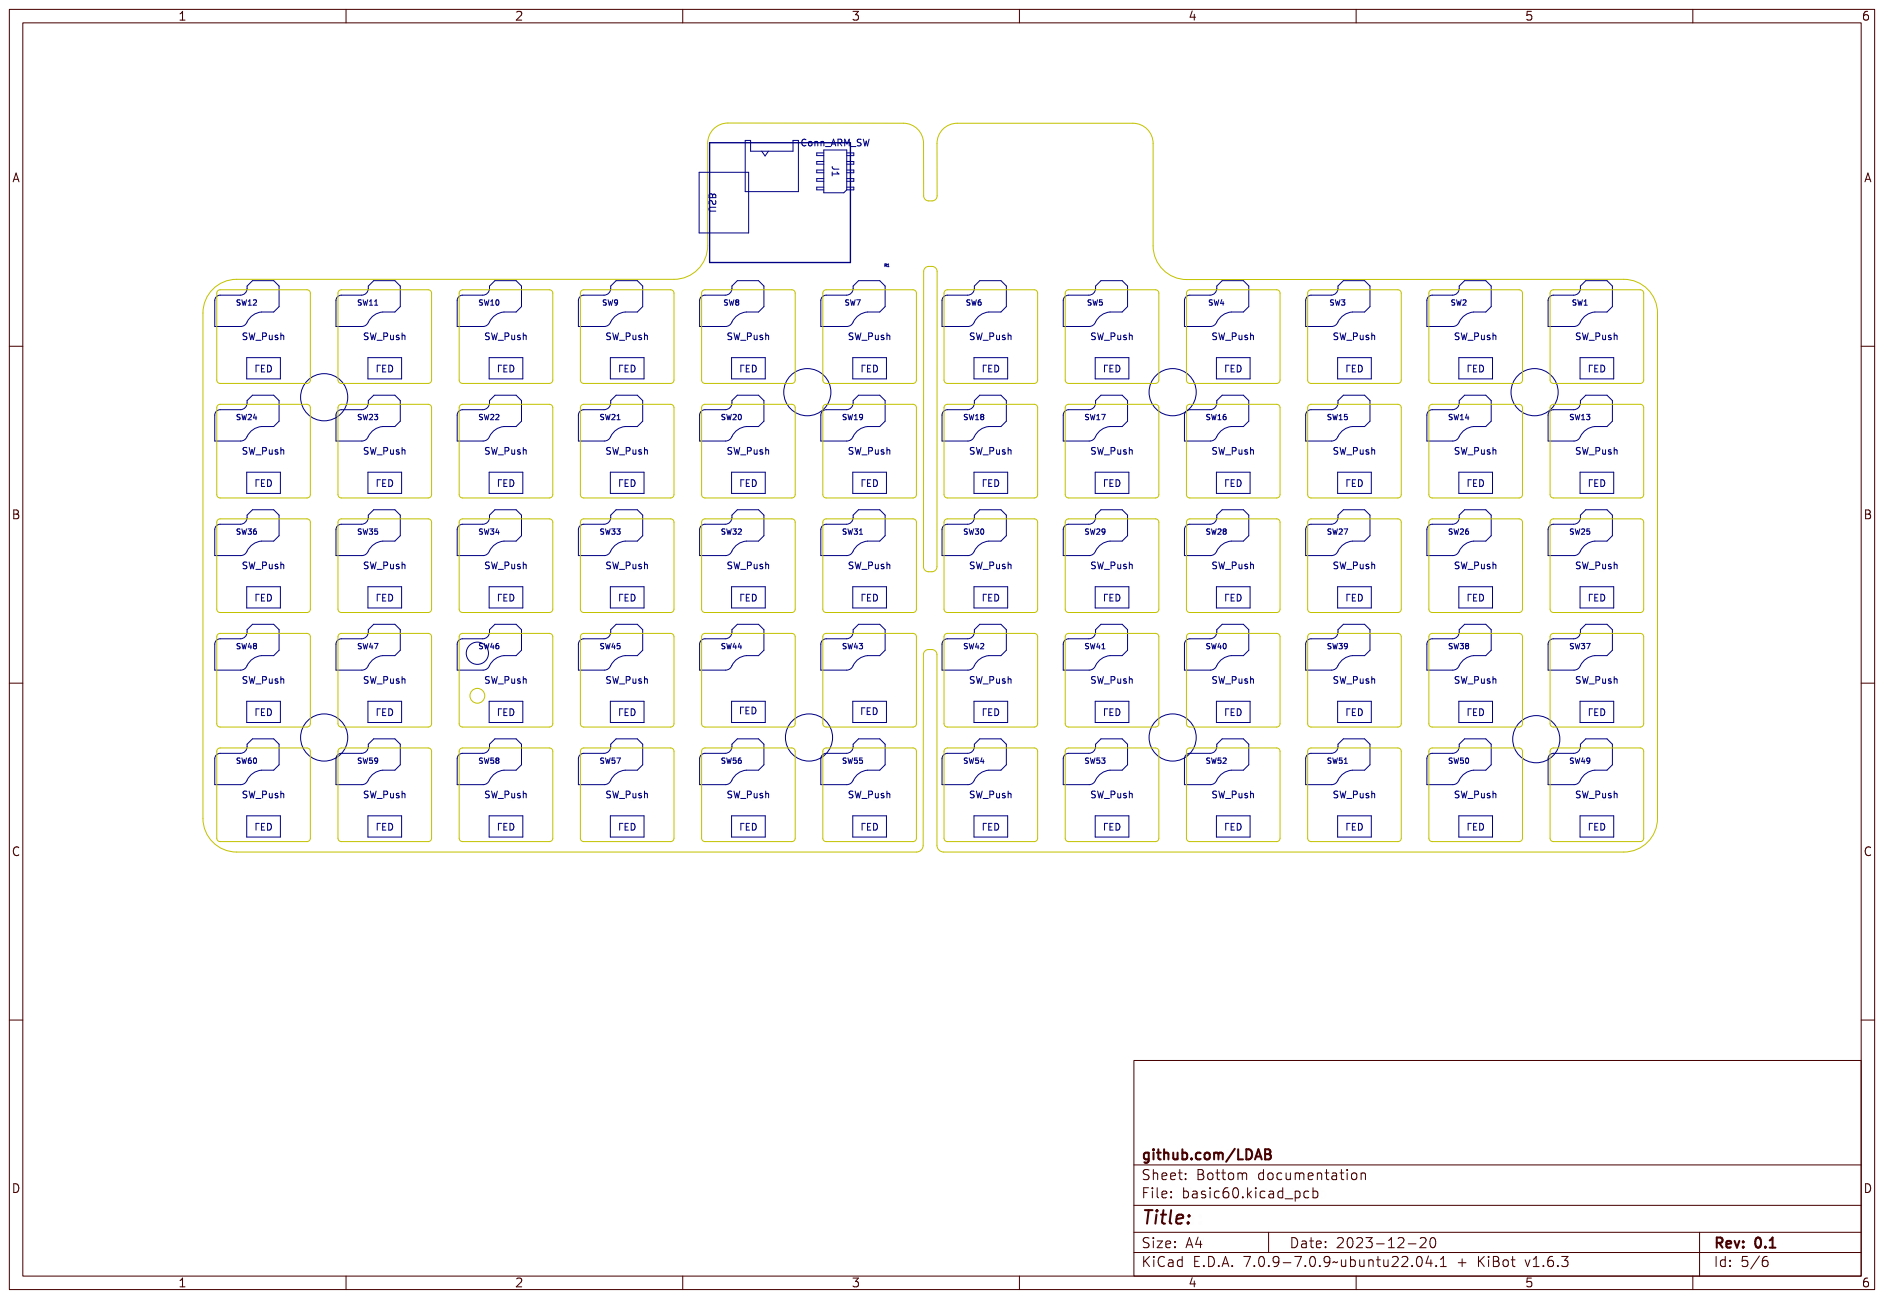
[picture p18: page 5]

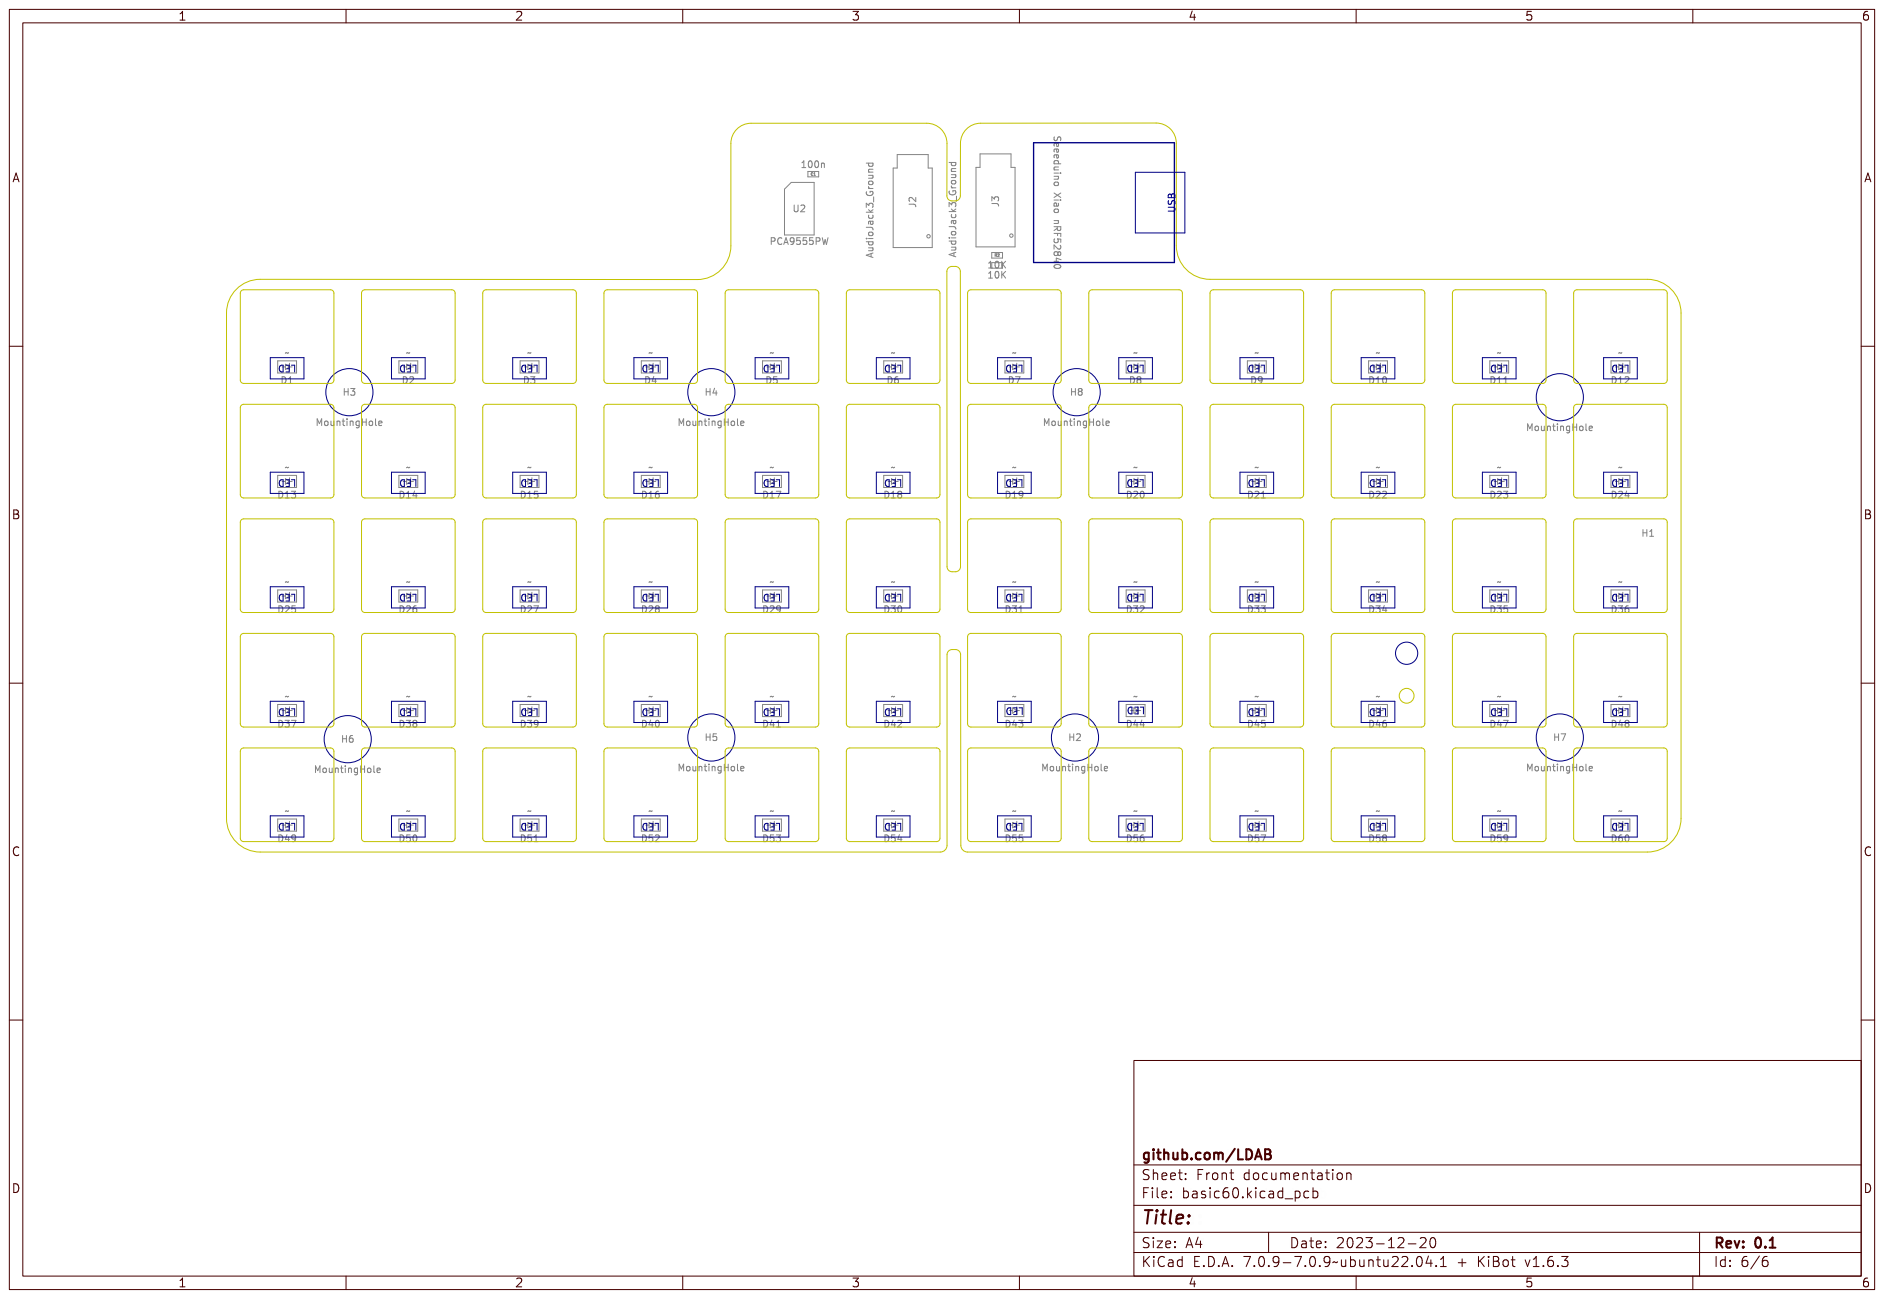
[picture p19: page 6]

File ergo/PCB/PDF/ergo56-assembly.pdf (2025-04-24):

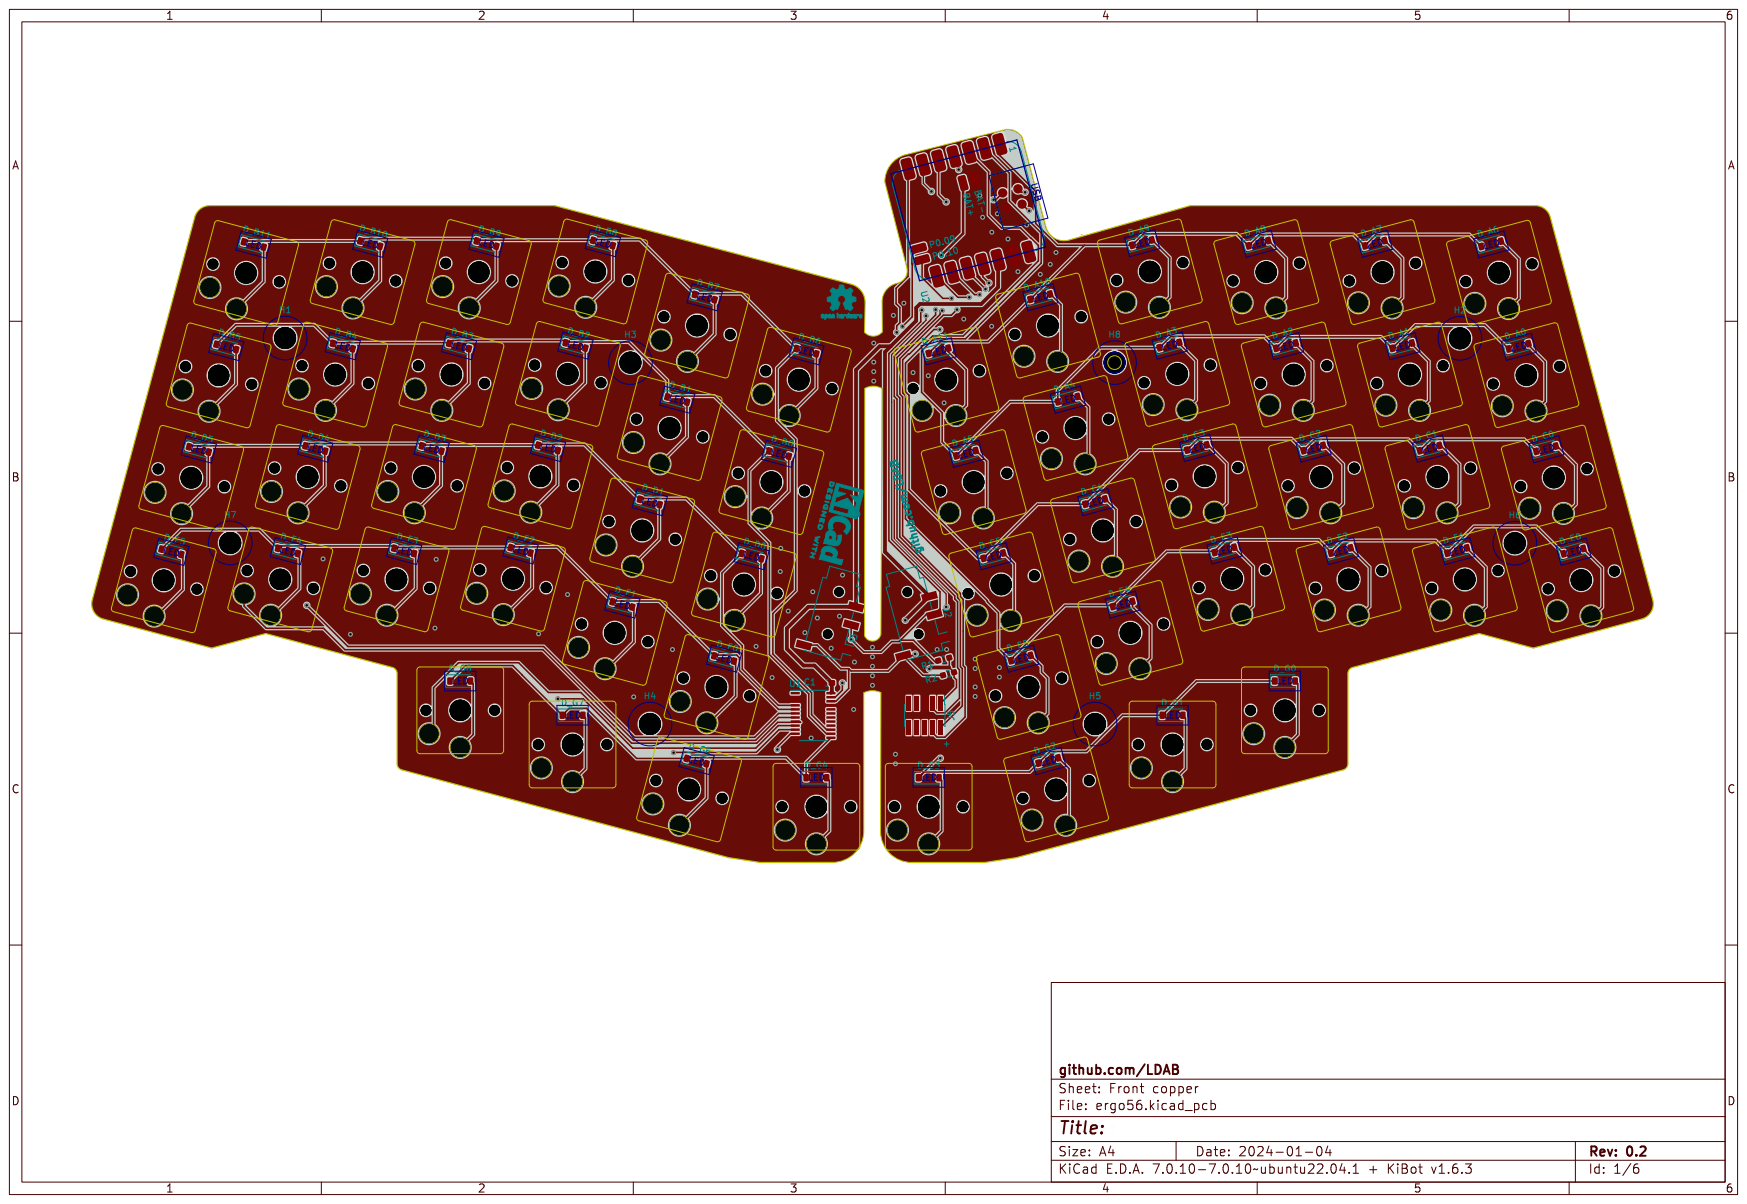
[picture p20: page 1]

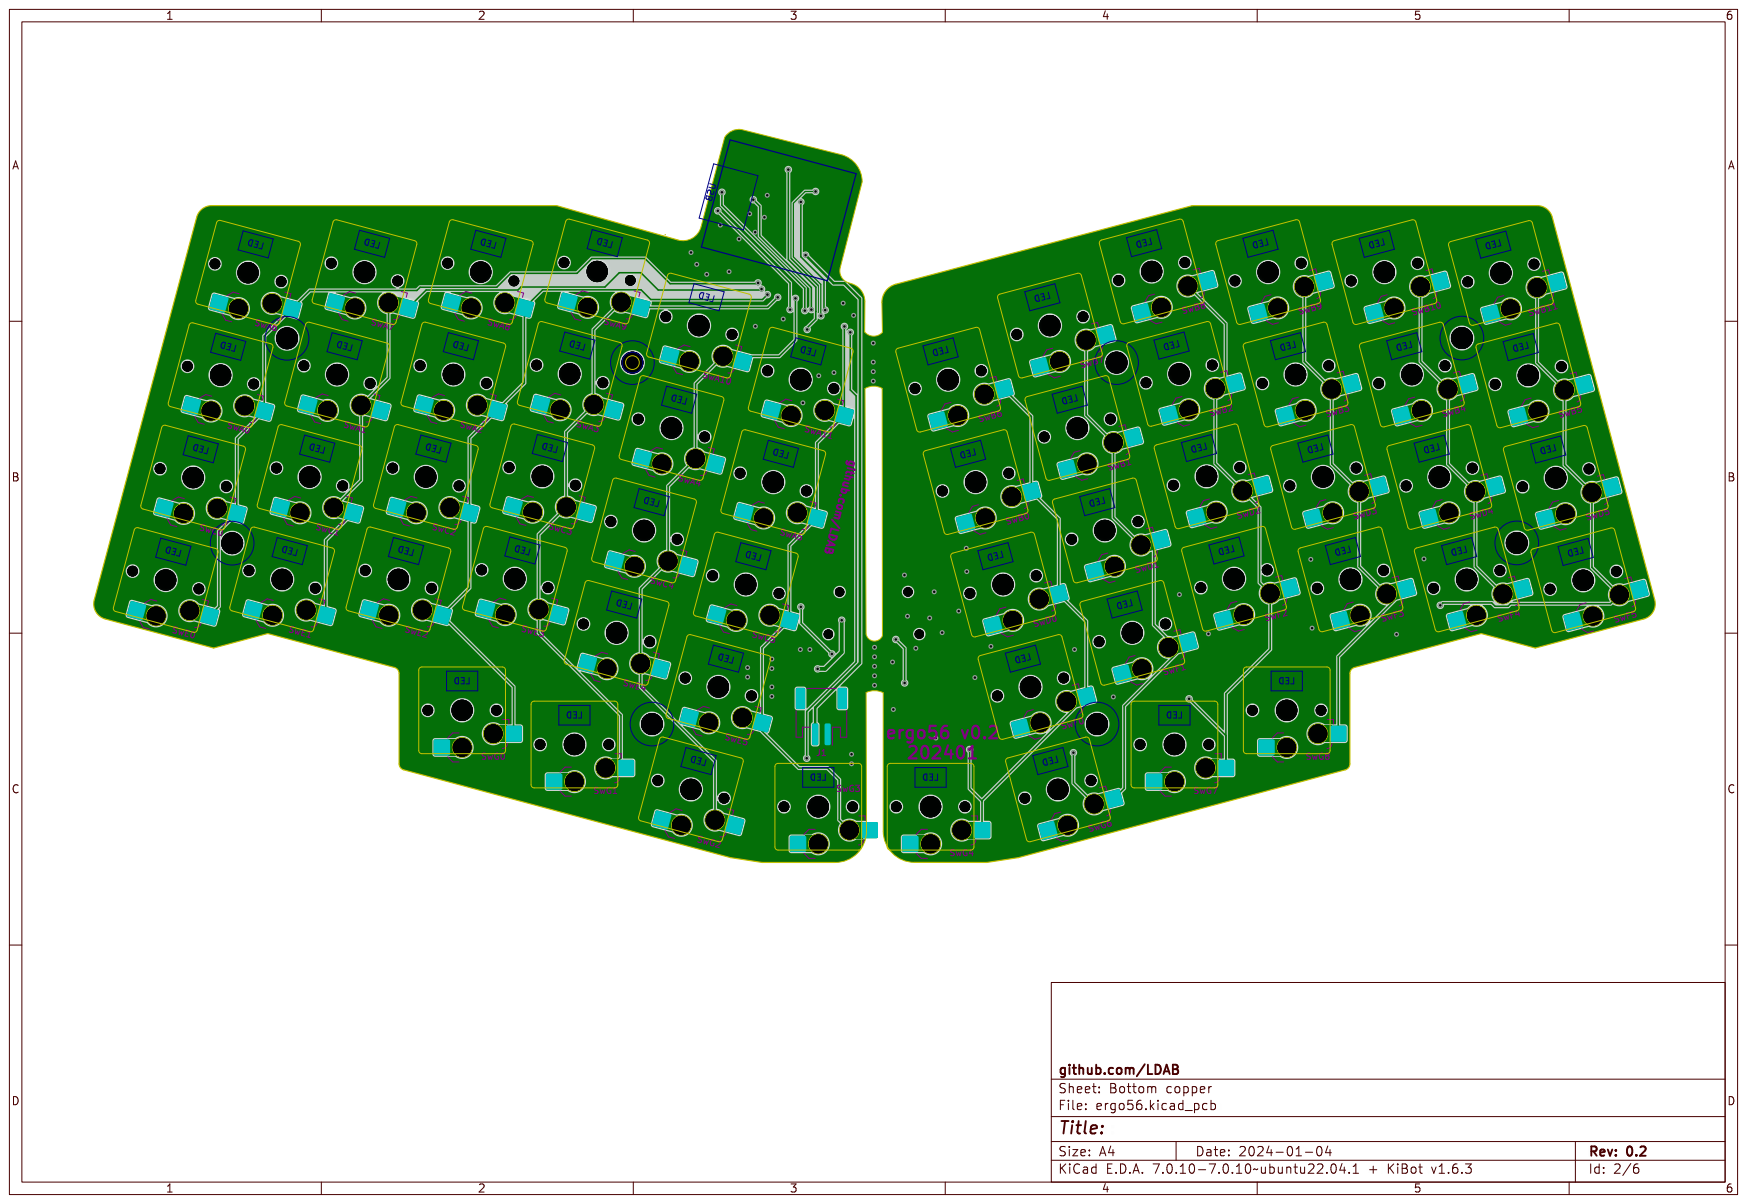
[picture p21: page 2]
ergo56 v0.2 202401; SwE0; SwE1; SwE2; SwE3; SwD3 SwD4 SwD5; SwD1; SwD0; SwC5; SwB0 SwD2; SwC4; SwC0; SwC1; SwC2; SwC3; SwB5; SwG2; SwB4; SwA0; SwA4; SwA3; SwB1; SwF0; SwA1; SwB2 SwB3; SwF2 SwF3 SwF4 SwF5; SwF1; SwE5; SwE4; SwA2; SwA5; SwG1; SwG6; SwG7; SwG4; SwG0; SwA6; SwA7; SwB9; SwG8; SwB11; SwA9; SwA11; SwB7; SwB8 SwB10; SwA8; SwA10; SwG3; SwB6; USB

github.com/LDAB
Sheet: Bottom copper
File: ergo56.kicad_pcb
Title:

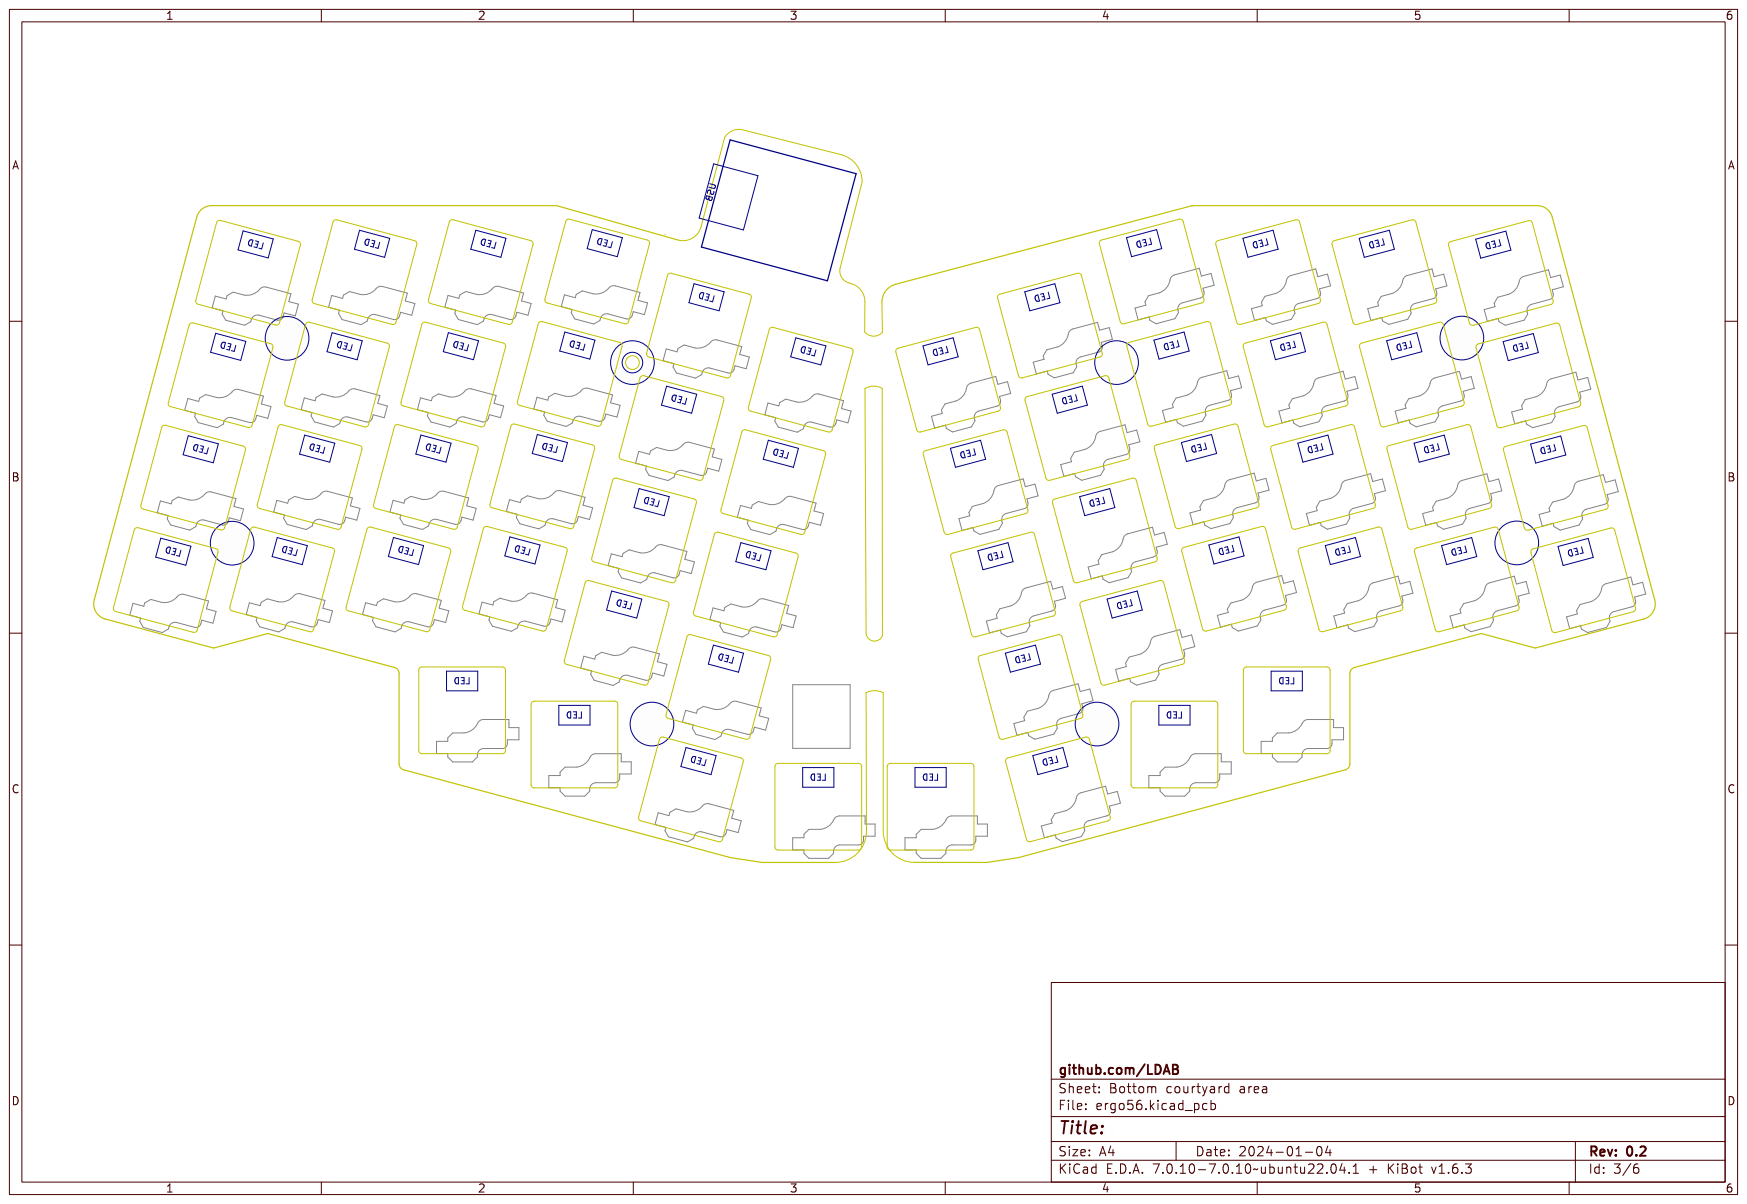
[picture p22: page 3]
USB; LED; LED LED; Sheet:; Bottom courtyard area

github.com/LDAB
File: ergo56.kicad_pcb
Title:

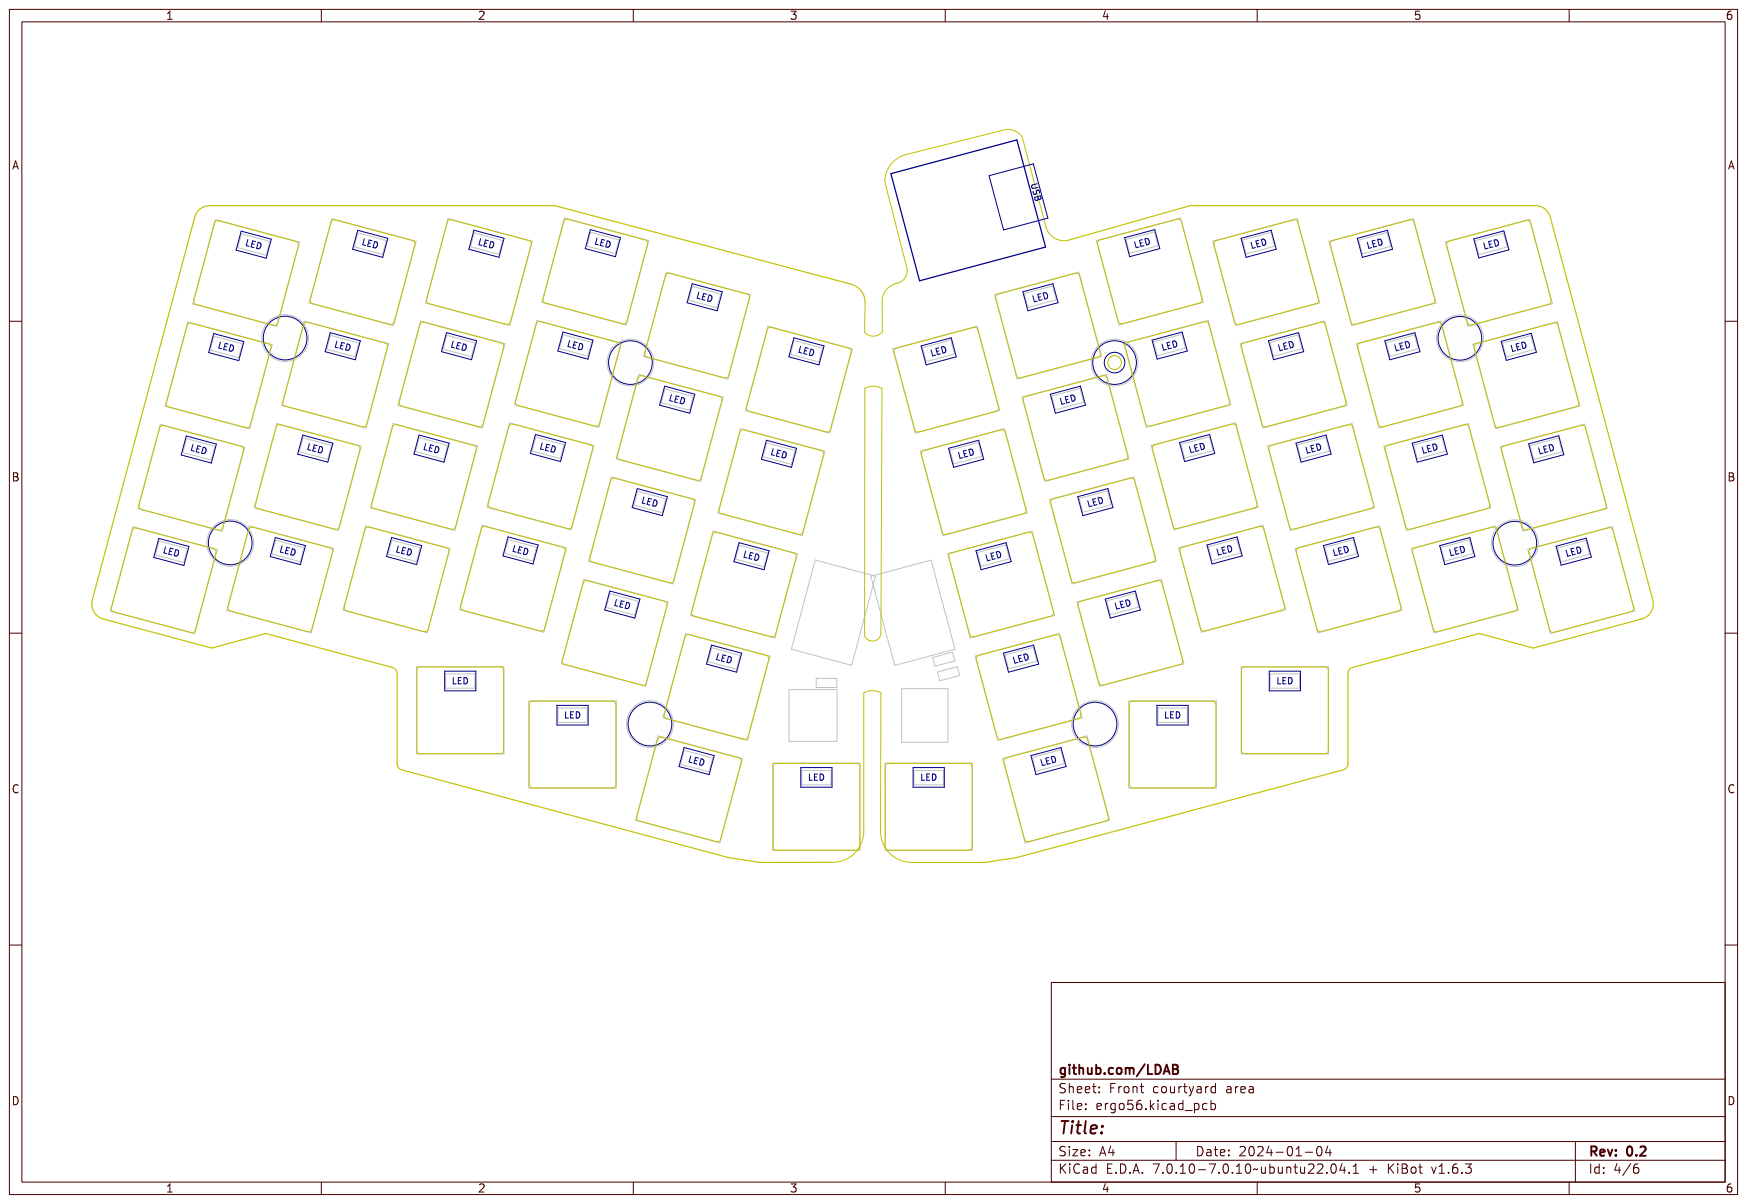
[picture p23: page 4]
USB; LED LED; LED; Sheet:; Front courtyard area

LED LED LED

github.com/LDAB
File: ergo56.kicad_pcb
Title:

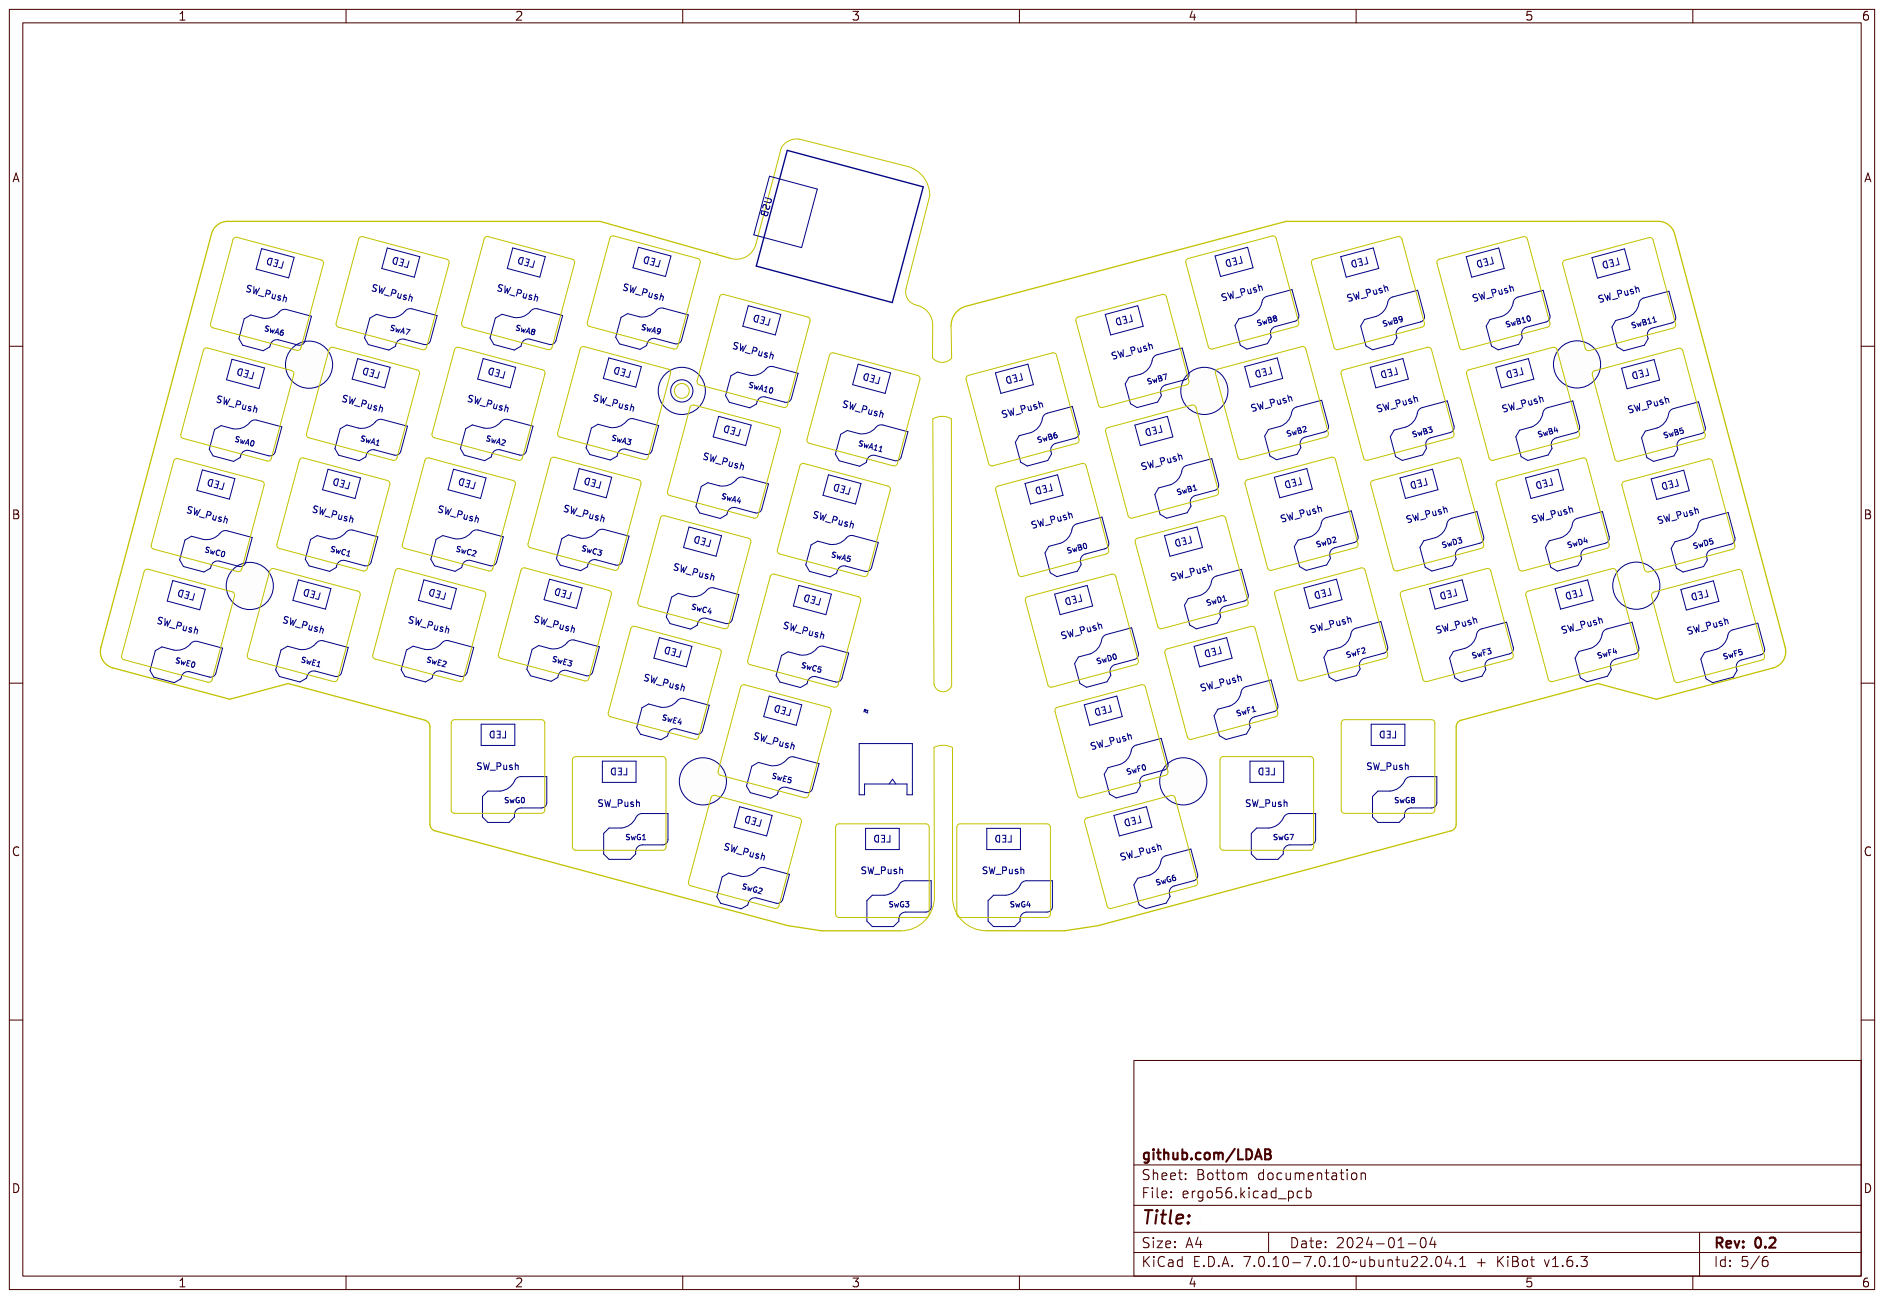
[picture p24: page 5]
SW_Push; SwG1; SwG7; SwG4; SwG0; SwG8; SwG3; USB

github.com/LDAB
Sheet: Bottom documentation
File: ergo56.kicad_pcb
Title:

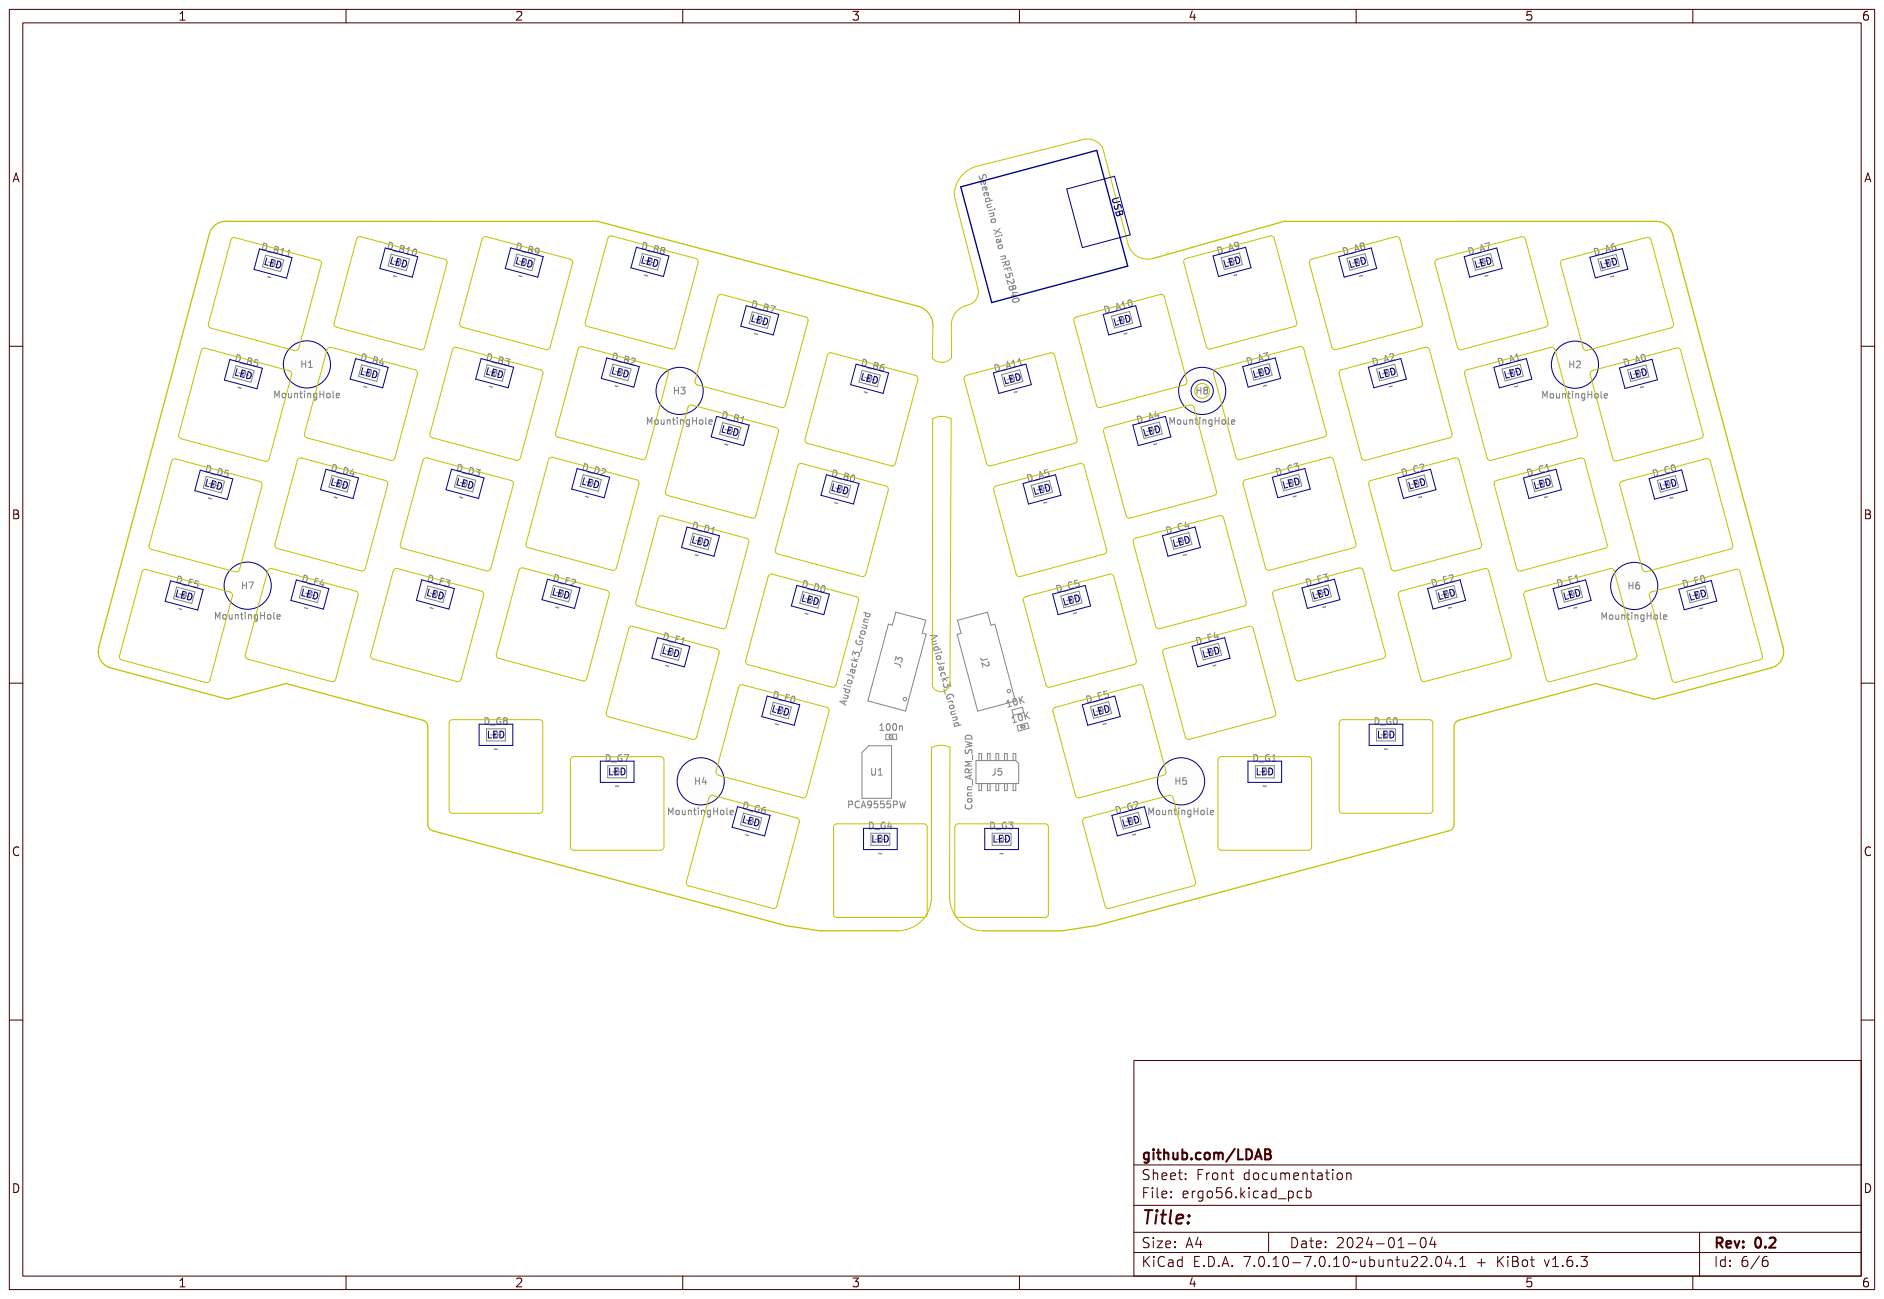
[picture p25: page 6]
D_E4 AudioJack3_Ground J3; MountingHole; Conn_ARM_SWD J5; AudioJack3_Ground; PCA9555PW; Seeeduino Xiao nRF52840; USB; LED LED; LED

LED LED LED

github.com/LDAB
Sheet: Front documentation
File: ergo56.kicad_pcb
Title:

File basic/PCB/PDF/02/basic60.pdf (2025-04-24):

Size: A4; Rev: 0.1; Date: 2023-12-20

github.com/LDAB
Sheet: Bottom copper
File: basic60.kicad_pcb
Title:
KiCad E.D.A. 7.0.9-7.0.9~ubuntu22.04.1 + KiBot v1.6.3

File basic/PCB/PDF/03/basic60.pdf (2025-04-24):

Sheet:; Bottom courtyard area; File:; basic60.kicad_pcb; Size: A4; Rev: 0.1; KiCad; E.D.A. 7.0.9-7.0.9~ubuntu22.04.1 + KiBot v1.6.3; Date: 2023-12-20

github.com/LDAB
Title:


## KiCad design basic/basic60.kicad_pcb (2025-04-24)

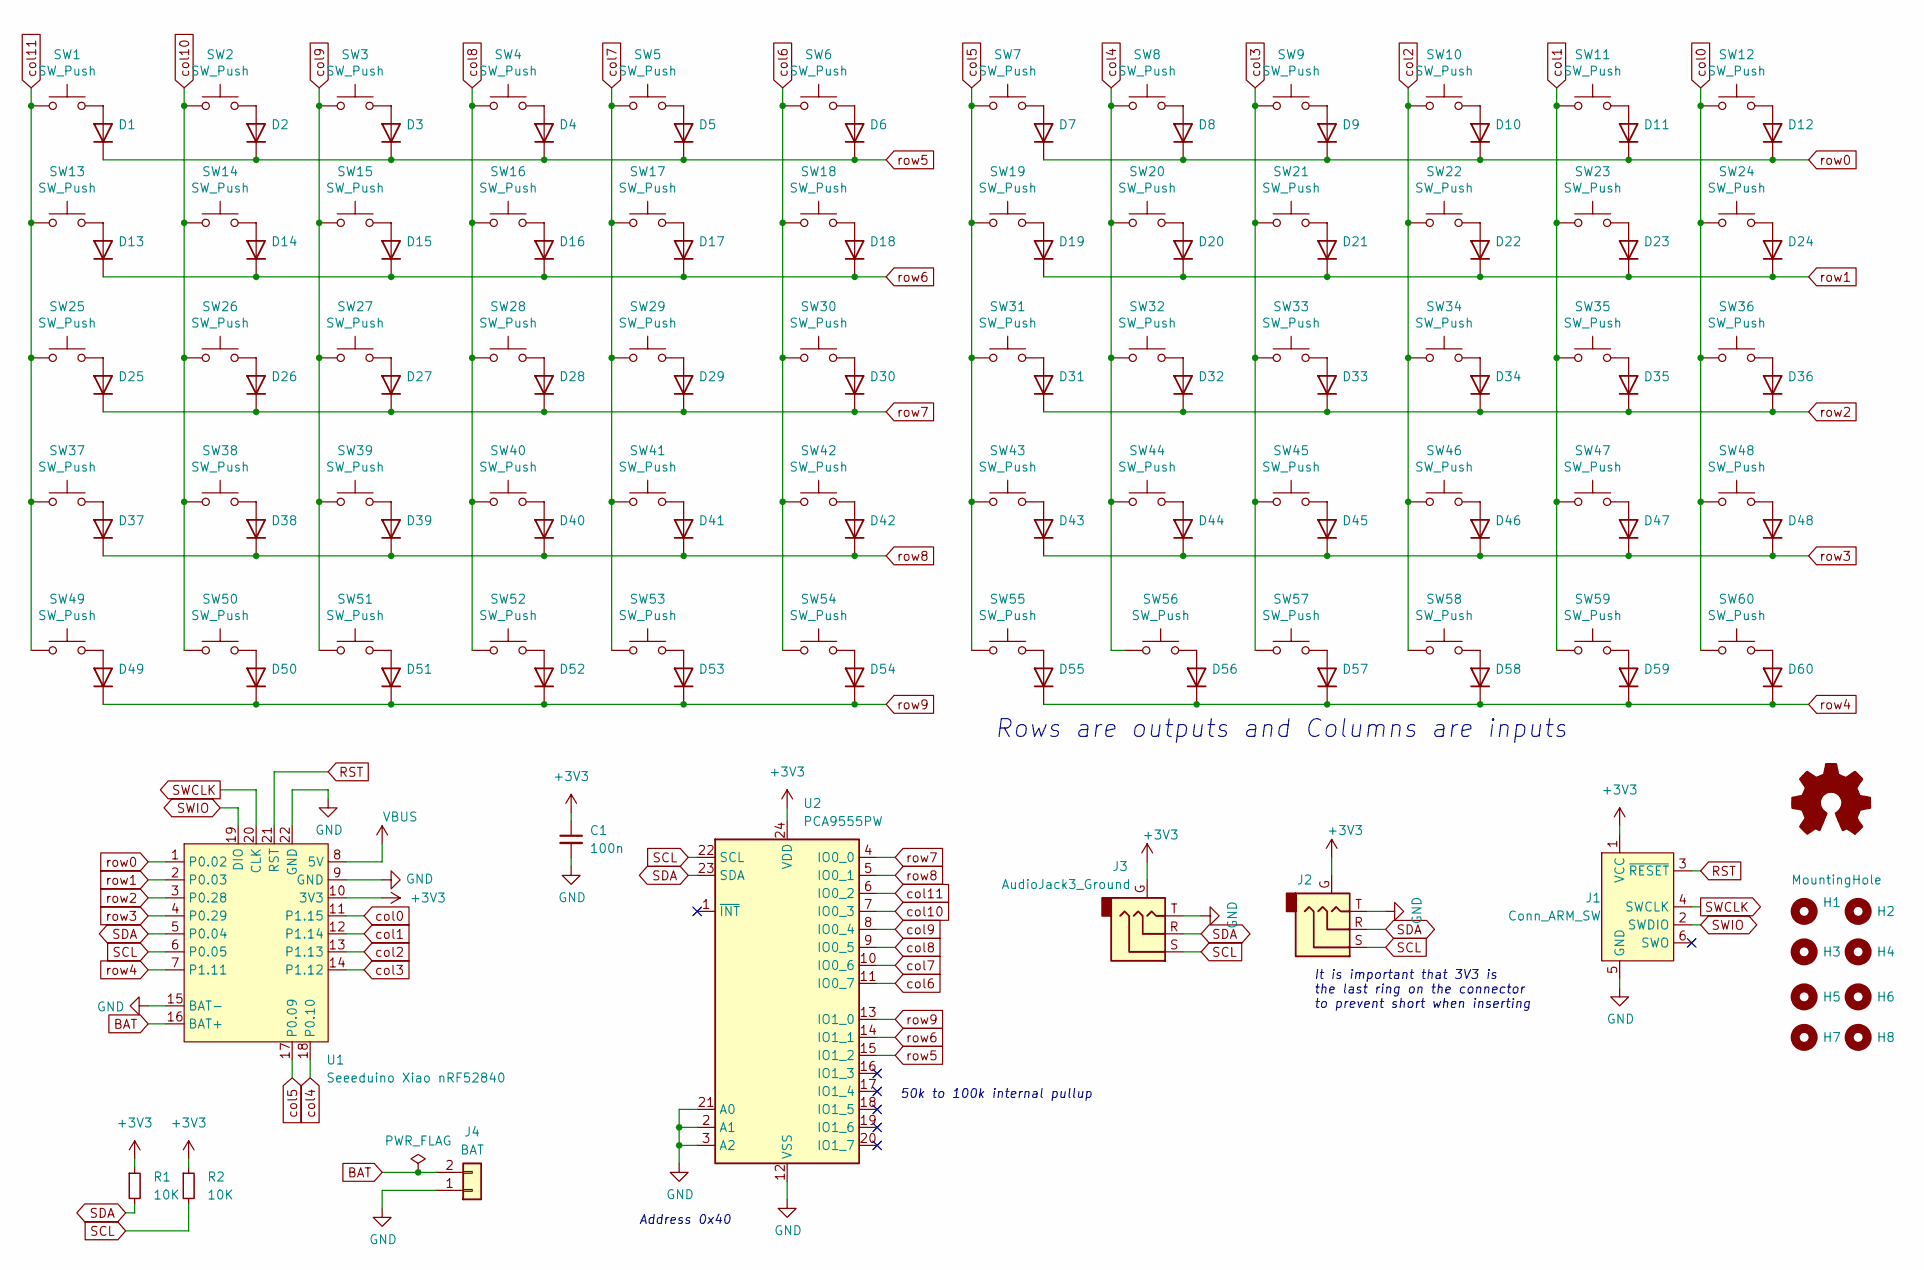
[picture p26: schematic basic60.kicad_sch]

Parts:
C1: 100n; C_0603_1608Metric_Pad1.08x0.95mm_HandSolder
D1, D2, D3, D4, D5, D6, D7, D8, D9, D10, D11, D12, D13, D14, D15, D16, D17, D18, D19, D20, D21, D22, D23, D24, D25, D26, D27, D28, D29, D30, D31, D32, D33, D34, D35, D36, D37, D38, D39, D40, D41, D42, D43, D44, D45, D46, D47, D48, D49, D50, D51, D52, D53, D54, D55, D56, D57, D58, D59, D60: D_SOD-123
H1, H2, H3, H4, H5, H6, H7, H8: MountingHole; MountingHole_3.5mm
J1: Conn_ARM_SW; PinHeader_2x05_P1.27mm_Vertical_SMD
J2, J3: AudioJack3_Ground; Jack_3.5mm_PJ320D_Horizontal
J4: BAT; JST_PH_S2B-PH-SM4-TB_1x02-1MP_P2.00mm_Horizontal
R1, R2: 10K; R_0603_1608Metric_Pad0.98x0.95mm_HandSolder
SW1, SW2, SW3, SW4, SW5, SW6, SW7, SW8, SW9, SW10, SW11, SW12, SW13, SW14, SW15, SW16, SW17, SW18, SW19, SW20, SW21, SW22, SW23, SW24, SW25, SW26, SW27, SW28, SW29, SW30, SW31, SW32, SW33, SW34, SW35, SW36, SW37, SW38, SW39, SW40, SW41, SW42, SW43, SW44, SW45, SW46, SW47, SW48, SW49, SW50, SW51, SW52, SW53, SW54, SW55, SW56, SW57, SW58, SW59, SW60: SW_Push; SW_choc_v1_HS_1u
U1: Seeeduino Xiao nRF52840; Xiao_nRF52840_AC_Reflow
U2: PCA9555PW; TSSOP-24_4.4x7.8mm_P0.65mm

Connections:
+3V3: C1.1, J1.1 (VCC), J2.G, J3.G, R1.1, R2.1, U1.10 (3V3), U2.24 (VDD)
BAT: J4.2, U1.16 (BAT+)
GND: C1.2, J1.5 (GND), J2.T, J3.T, J4.1, U1.9 (GND), U1.15 (BAT-), U1.22 (GND), U2.2 (A1), U2.3 (A2), U2.12 (VSS), U2.21 (A0)
unnamed: D1.2 (A), SW1.2
unnamed: D2.2 (A), SW2.2
unnamed: D3.2 (A), SW3.2
unnamed: D4.2 (A), SW4.2
unnamed: D5.2 (A), SW5.2
unnamed: D6.2 (A), SW6.2
unnamed: D7.2 (A), SW7.2
unnamed: D8.2 (A), SW8.2
unnamed: D9.2 (A), SW9.2
unnamed: D10.2 (A), SW10.2
unnamed: D11.2 (A), SW11.2
unnamed: D12.2 (A), SW12.2
unnamed: D13.2 (A), SW13.2
unnamed: D14.2 (A), SW14.2
unnamed: D15.2 (A), SW15.2
unnamed: D16.2 (A), SW16.2
unnamed: D17.2 (A), SW17.2
unnamed: D18.2 (A), SW18.2
unnamed: D19.2 (A), SW19.2
unnamed: D20.2 (A), SW20.2
unnamed: D21.2 (A), SW21.2
unnamed: D22.2 (A), SW22.2
unnamed: D23.2 (A), SW23.2
unnamed: D24.2 (A), SW24.2
unnamed: D25.2 (A), SW25.2
unnamed: D26.2 (A), SW26.2
unnamed: D27.2 (A), SW27.2
unnamed: D28.2 (A), SW28.2
unnamed: D29.2 (A), SW29.2
unnamed: D30.2 (A), SW30.2
unnamed: D31.2 (A), SW31.2
unnamed: D32.2 (A), SW32.2
unnamed: D33.2 (A), SW33.2
unnamed: D34.2 (A), SW34.2
unnamed: D35.2 (A), SW35.2
unnamed: D36.2 (A), SW36.2
unnamed: D37.2 (A), SW37.2
unnamed: D38.2 (A), SW38.2
unnamed: D39.2 (A), SW39.2
unnamed: D40.2 (A), SW40.2
unnamed: D41.2 (A), SW41.2
unnamed: D42.2 (A), SW42.2
unnamed: D43.2 (A), SW43.2
unnamed: D44.2 (A), SW44.2
unnamed: D45.2 (A), SW45.2
unnamed: D46.2 (A), SW46.2
unnamed: D47.2 (A), SW47.2
unnamed: D48.2 (A), SW48.2
unnamed: D49.2 (A), SW49.2
unnamed: D50.2 (A), SW50.2
unnamed: D51.2 (A), SW51.2
unnamed: D52.2 (A), SW52.2
unnamed: D53.2 (A), SW53.2
unnamed: D54.2 (A), SW54.2
unnamed: D55.2 (A), SW55.2
unnamed: D56.2 (A), SW56.2
unnamed: D57.2 (A), SW57.2
unnamed: D58.2 (A), SW58.2
unnamed: D59.2 (A), SW59.2
unnamed: D60.2 (A), SW60.2
RST: J1.3 (~RESET), U1.21 (RST)
SCL: J2.S, J3.S, R2.2, U1.6 (P0.05), U2.22 (SCL)
SDA: J2.R, J3.R, R1.2, U1.5 (P0.04), U2.23 (SDA)
SWCLK: J1.4 (SWCLK), U1.20 (CLK)
SWIO: J1.2 (SWDIO), U1.19 (DIO)
VBUS: U1.8 (5V)
col0: SW12.1, SW24.1, SW36.1, SW48.1, SW60.1, U1.11 (P1.15)
col1: SW11.1, SW23.1, SW35.1, SW47.1, SW59.1, U1.12 (P1.14)
col2: SW10.1, SW22.1, SW34.1, SW46.1, SW58.1, U1.13 (P1.13)
col3: SW9.1, SW21.1, SW33.1, SW45.1, SW57.1, U1.14 (P1.12)
col4: SW8.1, SW20.1, SW32.1, SW44.1, SW56.1, U1.18 (P0.10)
col5: SW7.1, SW19.1, SW31.1, SW43.1, SW55.1, U1.17 (P0.09)
col6: SW6.1, SW18.1, SW30.1, SW42.1, SW54.1, U2.11 (IO0_7)
col7: SW5.1, SW17.1, SW29.1, SW41.1, SW53.1, U2.10 (IO0_6)
col8: SW4.1, SW16.1, SW28.1, SW40.1, SW52.1, U2.9 (IO0_5)
col9: SW3.1, SW15.1, SW27.1, SW39.1, SW51.1, U2.8 (IO0_4)
col10: SW2.1, SW14.1, SW26.1, SW38.1, SW50.1, U2.7 (IO0_3)
col11: SW1.1, SW13.1, SW25.1, SW37.1, SW49.1, U2.6 (IO0_2)
row0: D7.1 (K), D8.1 (K), D9.1 (K), D10.1 (K), D11.1 (K), D12.1 (K), U1.1 (P0.02)
row1: D19.1 (K), D20.1 (K), D21.1 (K), D22.1 (K), D23.1 (K), D24.1 (K), U1.2 (P0.03)
row2: D31.1 (K), D32.1 (K), D33.1 (K), D34.1 (K), D35.1 (K), D36.1 (K), U1.3 (P0.28)
row3: D43.1 (K), D44.1 (K), D45.1 (K), D46.1 (K), D47.1 (K), D48.1 (K), U1.4 (P0.29)
row4: D55.1 (K), D56.1 (K), D57.1 (K), D58.1 (K), D59.1 (K), D60.1 (K), U1.7 (P1.11)
row5: D1.1 (K), D2.1 (K), D3.1 (K), D4.1 (K), D5.1 (K), D6.1 (K), U2.15 (IO1_2)
row6: D13.1 (K), D14.1 (K), D15.1 (K), D16.1 (K), D17.1 (K), D18.1 (K), U2.14 (IO1_1)
row7: D25.1 (K), D26.1 (K), D27.1 (K), D28.1 (K), D29.1 (K), D30.1 (K), U2.4 (IO0_0)
row8: D37.1 (K), D38.1 (K), D39.1 (K), D40.1 (K), D41.1 (K), D42.1 (K), U2.5 (IO0_1)
row9: D49.1 (K), D50.1 (K), D51.1 (K), D52.1 (K), D53.1 (K), D54.1 (K), U2.13 (IO1_0)

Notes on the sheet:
It is important that 3V3 is the last ring on the connector to prevent short when inserting
Address 0x40
50k to 100k internal pullup
Rows are outputs and Columns are inputs

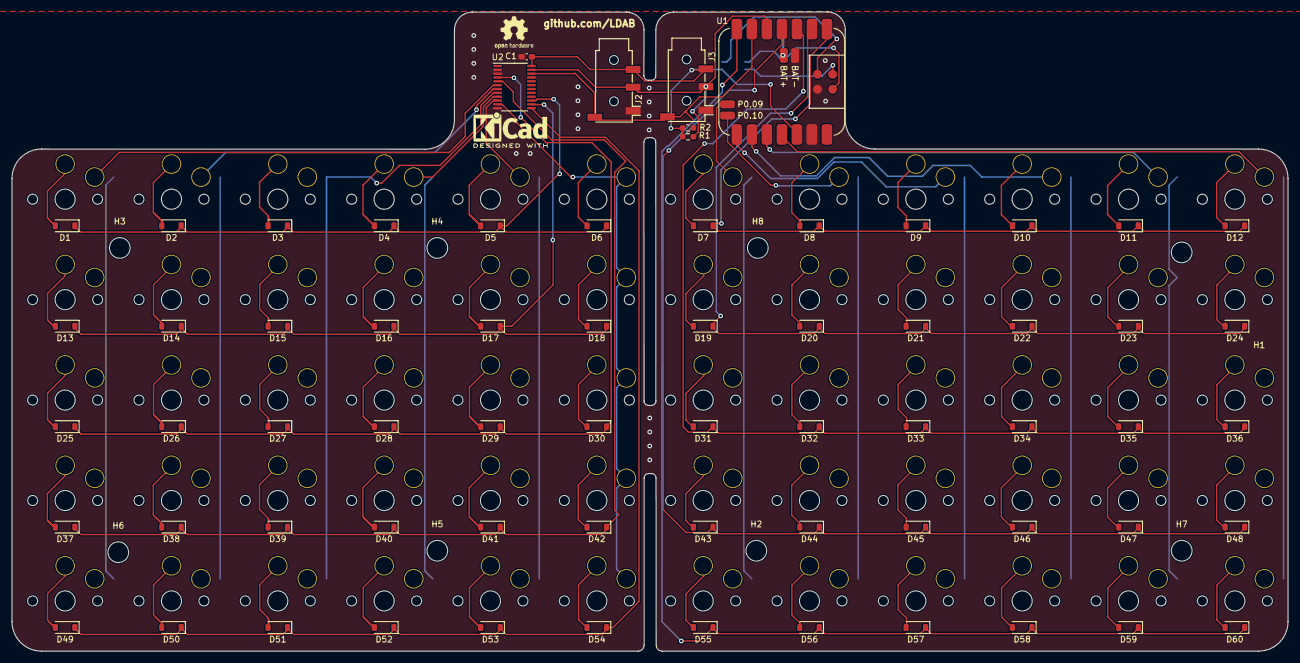
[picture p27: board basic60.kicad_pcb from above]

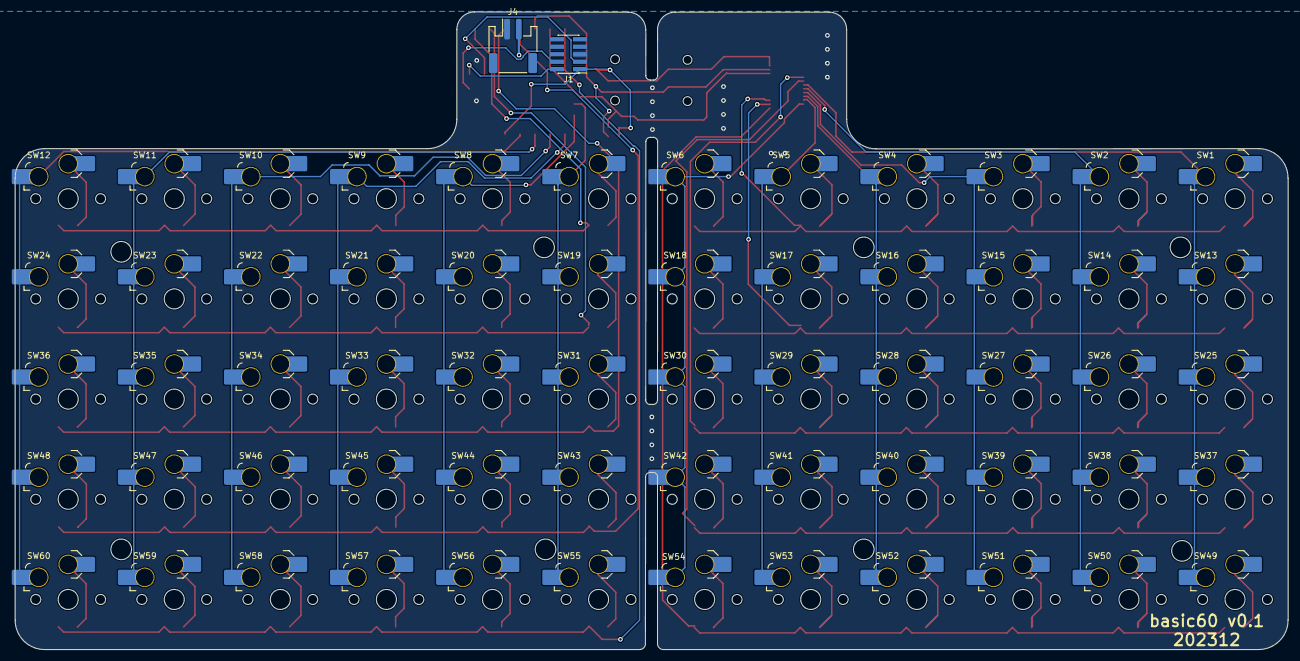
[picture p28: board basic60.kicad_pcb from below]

Board: 2 copper layers, 216.0 x 108.2 mm, 137 parts (62 on the bottom side), 90 nets.

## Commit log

2025-04-24 Pooling FW
    [Kailh Choc FunkMonk 1u.step, Kailh Choc Low Profile Switch.step, audio_3.5mm_trrs.STEP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]
2026-01-26 Update board configuration in build.yaml to use 'xiao_ble'

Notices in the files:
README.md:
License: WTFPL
